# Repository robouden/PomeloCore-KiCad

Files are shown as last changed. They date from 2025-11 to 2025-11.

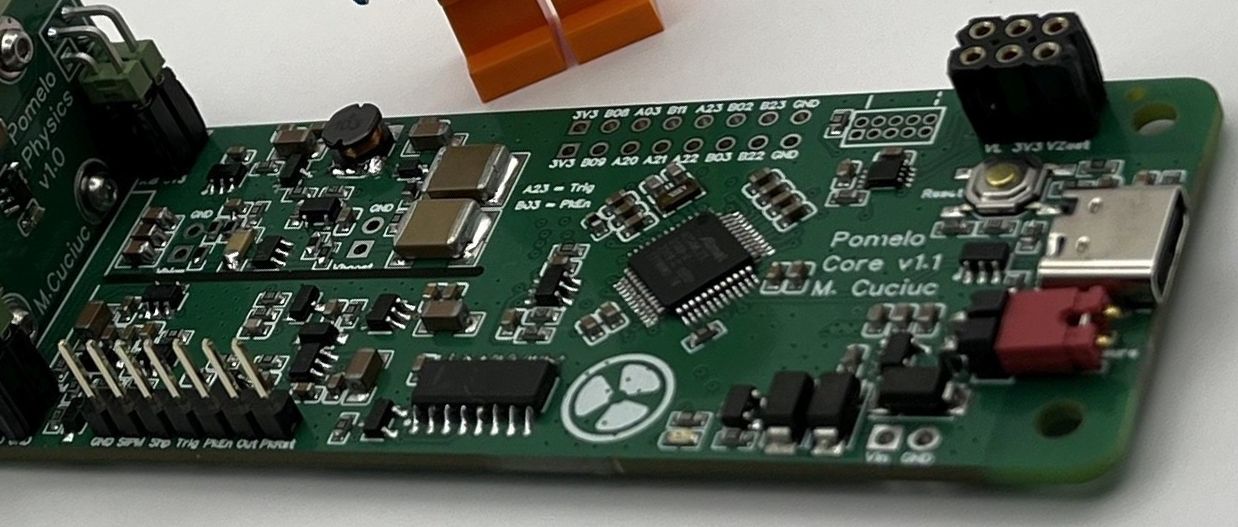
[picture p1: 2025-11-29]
Polemo Core/bGeigieScint/Images/top view 1.jpg

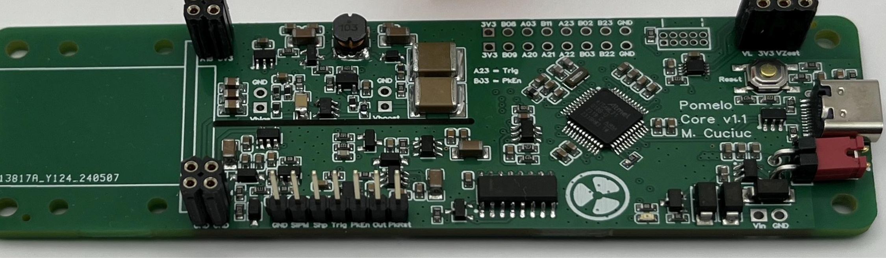
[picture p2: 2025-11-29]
Polemo Core/bGeigieScint/Images/top view 2.jpg

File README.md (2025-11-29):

# Pomelo Core





**Pomelo Core** is a compact radiation detection board featuring a Silicon Photomultiplier (SiPM) based sensor system with integrated high-voltage generation, analog signal processing, and USB connectivity.

## 📋 Features

- **Microcontroller**: ATSAML21G18B (ARM Cortex-M0+, 256KB Flash, 32KB RAM)
- **SiPM Interface**: Complete analog frontend with adjustable HV bias (30-70V)
- **Power Management**: Multi-rail power supply (3.3V, 3.0V, Vload, Vbias)
- **Connectivity**: USB-C interface with ESD protection
- **Debug**: 10-pin J-LINK SWD interface + 18 test points
- **Expansion**: Multiple GPIO headers for external interfaces
- **Compact**: 40mm × 100mm 4-layer PCB

## 🔧 Hardware Specifications

### Main Components

| Component | Part Number | Function |
|---|---|---|
| MCU | ATSAML21G18B-AUT | Main microcontroller (48-pin QFN) |
| USB | USB3.1C16PFSMT | USB-C connector (USB 2.0) |
| LDO 3.3V | XC6209F332MR-G | Main 3.3V regulator |
| LDO 3.0V | TPS7A2030PDBVR | 3.0V rail for analog |
| LDO Vload | LT3014BHVES5 | Low-noise LDO for HV control |
| OpAmp | OPA357AIDBVR | Shaper amplifier |
| Comparator | TLV3201AIDBVT | Fast comparator |
| Latch | MC14043BDR2G | Digital latch for triggering |

### SiPM Sensor

- **Part Number**: AFBR-S4N44P014M (Broadcom)
- **Type**: NUV-HD Silicon Photomultiplier
- **Active Area**: 4×4 mm²
- **Spectral Range**: 350-900 nm (peak sensitivity ~420 nm)
- **Datasheet**: [AFBR-S4N44P014M Documentation](https://docs.broadcom.com/doc/AFBR-S4N44P014M-NUV-MT-Silicon-Photomultiplier)

### Scintillator Crystal

- **Material**: CsI(Tl) - Cesium Iodide doped with Thallium
- **Dimensions**: 10 mm × 10 mm × 20 mm
- **Emission Peak**: ~550 nm (matches SiPM sensitivity)
- **Application**: Gamma ray detection coupled to SiPM

### Power Supply

- **Input**: 4.5-6V via USB-C or external connector
- **Output Rails**:
  - 3.3V @ up to 200mA (digital)
  - 3.0V @ up to 100mA (analog)
  - Vload (adjustable)
  - Vbias: 30-70V @ low current (SiPM bias)

### HV Generation

The board features an integrated **boost converter + linear regulator** topology for SiPM bias generation:

- **Boost Stage**: PWM-controlled (L1 10mH inductor, Q3 P-FET, D9 Schottky)
- **Regulation**: LT3014 ultra-low-noise LDO
- **Control**: MCU DAC output (PA02_DAC_HV) sets target voltage
- **Monitoring**: Comparator feedback (PB10_HV_COMP_OUT)
- **Output**: Adjustable 30-70V Vbias for SiPM

## 📁 Project Structure

```
PomeloCore-KiCad/
├── Polemo Core/
│   └── Polemo Core 2/
│       ├── Polemo Core 2.kicad_pro       # KiCad project file
│       ├── Polemo Core 2.kicad_sch       # Schematic (organized in functional blocks)
│       ├── Polemo Core 2.kicad_pcb       # PCB layout (4-layer, 40×100mm)
│       └── Polemo Core 2-backups/        # Automatic backups
├── BOM.csv                                # Bill of Materials
├── v1_2/                                  # Version 1.2 reference files
│   └── schematic/
│       └── PomeloCore.pdf                 # V1.2 schematic PDF
└── README.md                              # This file
```

## 🎨 Schematic Organization

The schematic is organized into **7 functional blocks**:

1. **USB & POWER INPUT**: USB-C interface, power connectors, reset button
2. **POWER MANAGEMENT**: LDOs, inductors, power distribution
3. **MCU CORE**: Microcontroller, crystal, decoupling
4. **ANALOG FRONTEND**: SiPM signal chain, opamps, comparators
5. **LOGIC & CONTROL**: Digital logic, latches, level shifters
6. **EXPANSION I/O**: Pin headers for external connections
7. **DEBUG & TEST**: J-LINK interface, test points

## 🔌 Pinout & Interfaces

### J-LINK Debug Header (10-pin)
```
1: VCC        2: SWDIO
3: GND        4: SWCLK
5: GND        6: SWO
7: NC         8: NC
9: GND       10: RESET
```

### Expansion Headers

- **H2, H3**: 7-pin GPIO expansion
- **H5**: 7-pin expansion with labeled signals
- **MEAS1**: 2-pin measurement header
- **P1, P2**: 2×2 power connectors (mirrored on Pomelo Physics board)

### Key Signals

| Signal | Description |
|---|---|
| SiPM_A | SiPM analog input |
| Vbias | SiPM bias voltage output |
| SHAPER_OUT | Shaped pulse output |
| PA02_DAC_HV | HV control DAC output |
| PA10_PWM | Boost converter PWM |
| PB03_PEAKDET_EN | Peak detector enable |
| PA23_TRG_OUT | Trigger output |

## 📊 Version History

### V1.3 (Current)
**Major improvements over V1.2:**

✅ **Added (47 components)**:
- USB-C connector (USBC1)
- Reset button (BUT1)
- J-LINK debug header
- 18 test points (TP1-TP18)
- Additional transistors (Q4, Q5) and diodes (D6, D8, D10)
- 15 new resistors for better signal conditioning

✅ **Changed**:
- C44: 1uF → 4.7uF
- C45: 4.7uF → 1uF
- H2, H3: 6-pin → 7-pin headers (expanded)

✅ **Enhanced**:
- Better debugging capability
- Improved power filtering
- More flexible I/O expansion

### V1.2 (Legacy)
- Initial production version
- PDF schematic available in `v1_2/schematic/`

## 🚀 Getting Started

### Prerequisites

- **KiCad 9.0** or later
- Basic understanding of radiation detection and SiPM operation
- JTAG/SWD programmer (e.g., J-Link, ST-Link)

### Opening the Project

1. Clone this repository
2. Open `Polemo Core/Polemo Core 2/Polemo Core 2.kicad_pro` in KiCad
3. The schematic shows functional blocks with dashed rectangles
4. The PCB has components organized by function

### Manufacturing

**PCB Specifications:**
- **Layers**: 4 (signal/GND/VCC/signal)
- **Dimensions**: 40mm × 100mm
- **Thickness**: 1.6mm
- **Copper**: 35μm (1oz) on all layers
- **Min Track/Space**: 0.15mm / 0.15mm (for 0805 components)
- **Finish**: HASL or ENIG recommended
- **Solder Mask**: Green (top and bottom)

**Assembly Notes:**
- Minimum component size: 0805 for passives
- QFN-48 MCU requires reflow soldering
- LDOs are SOT-23-5 packages
- Test points for easy debugging

## 📝 Design Notes

### Power Planes
- **Layer 1 (In1.Cu)**: GND plane - solid pour for low noise
- **Layer 2 (In2.Cu)**: VCC plane - split for 3.3V/3.0V rails

### Critical Traces
- Keep SiPM analog traces short and shielded
- HV traces (Vbias) should be isolated from digital signals
- Crystal traces should be short with GND guard ring

### Component Placement
Components are organized into functional blocks:
- Power supply on left side
- MCU in center
- Analog section on right
- Digital logic bottom-right

## 🔬 Applications

- Radiation detection and measurement
- Scintillation counting
- Environmental monitoring
- Educational radiation physics
- DIY Geiger counter replacement with better sensitivity

## 👥 Credits

**Designer**: M. Cuciuc
**Organization**: Safecast
**Date**: 2024-2025

## 📄 License

This hardware design is open source. Please check individual files for specific license terms.

Firmware and software components may have separate licenses.

## 🤝 Contributing

Contributions are welcome! Please:

1. Fork the repository
2. Create a feature branch
3. Make your changes
4. Submit a pull request

For major changes, please open an issue first to discuss what you would like to change.

## 📞 Support

- **Project Page**: [Pomelo on Crowd Supply](https://www.crowdsupply.com/pomelo-instrumentation/pomelo)
- **Safecast**: [https://safecast.org](https://safecast.org)
- Report issues through the repository's issue tracker

## ⚠️ Safety Warning

This board generates **high voltage** (up to 70V) for SiPM biasing. Handle with care:
- Do not touch HV traces while powered
- Use proper ESD protection
- Follow safe electronics handling practices
- Designed for educational and research purposes

---

**Made with ❤️ for the radiation detection community**

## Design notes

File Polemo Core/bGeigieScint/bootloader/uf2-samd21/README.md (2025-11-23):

# UF2 Bootloader

This repository contains a bootloader, derived from Atmel's SAM-BA,
which in addition to the USB CDC (serial) protocol, also supports
the USB MSC (mass storage).

## Features this version

- Support Pomelo Core board

This is adapted from the SAML21 version of the UF2 bootloader found on [the ElectronicCats github](https://github.com/ElectronicCats/uf2-samd21)

## UF2

**UF2 (USB Flashing Format)** is a name of a file format, developed by Microsoft, that is particularly
suitable for flashing devices over MSC devices. The file consists
of 512 byte blocks, each of which is self-contained and independent
of others.

Each 512 byte block consist of (see `uf2format.h` for details):
* magic numbers at the beginning and at the end
* address where the data should be flashed
* size of data
* data (up to 476 bytes; for SAMD it's 256 and 128 bytes so it's easy to flash in one go)

Thus, it's really easy for the microcontroller to recognize a block of
a UF2 file is written and immediately write it to flash.

* **UF2 specification repo:** https://github.com/Microsoft/uf2
* [#DeskOfLadyada UF24U ! LIVE @adafruit #adafruit #programming](https://youtu.be/WxCuB6jxLs0)

## Features

* USB CDC (Serial emulation) monitor mode compatible with Arduino
  (including XYZ commands) and BOSSA flashing tool
* USB MSC interface for writing UF2 files
* reading of the contests of the flash as an UF2 file via USB MSC
* UART Serial (real serial wire) monitor mode (typically disabled due to space constraints)
* In-memory logging for debugging - use the `logs` target to extract the logs using `openocd`
* double-tap reset to stay in the bootloader mode
* automatic reset after UF2 file is written

## Board identification

Configuration files for board `foo` are in `boards/foo/board_config.h` and `board.mk`. You can
build it with `make BOARD=foo`. You can also create `Makefile.user` file with `BOARD=foo`
to change the default.

The board configuration specifies the USB vendor/product name and ID,
as well as the volume label (main thing that the operating systems show).

There is also `BOARD_ID`, which is meant to be machine-readable and specific
to a given version of board hardware. The programming environment might use
this to suggest packages to be imported (i.e., a package for a particular
external flash chip, SD card etc.).

These configuration values can be read from `INFO_UF2.TXT` file.
Presence of this file can be tested to see if the board supports `UF2` flashing,
while contest, particularly `Board-ID` field, can be used for feature detection.

The current flash contents of the board is exposed as `CURRENT.UF2` file.
This file includes the bootloader address space. The last word of bootloader
space points to the string holding the `INFO_UF2.TXT` file, so it can be parsed
by a programming environment to determine which board does the `.UF2` file comes from.

## Handover

When the user space application implements the USB MSC protocol, it's possible to
handover execution to the bootloader in the middle of MSC file transfer,
when the application detects that a UF2 block is written.

Details are being finalized.

## Bootloader update

The bootloader will never write to its own flash area directly.
However, the user code can write there.
Thus, to update the bootloader, one can ship a user-space program,
that contains the new version of the bootloader and copies it to the
appropriate place in flash.

Such a program is generated during build in files `update-bootloader*.uf2`.
If you're already running UF2 bootloader, the easiest way to update
it, is to just copy this file to the exposed MSD drive.

The build also generates `update-bootloader*.ino` with an equivalent Arduino
sketch. You can copy&paste it into Arduino IDE and upload it to the device.

## Fuses

### SAMD21

The SAMD21 supports a `BOOTPROT` fuse, which write-protects the flash area of
the bootloader. Changes to this fuse only take effect after device reset.

OpenOCD exposes `at91samd bootloader` command to set this fuse. **This command is buggy.**
It seems to reset both fuse words to `0xffffffff`, which prevents the device
from operating correctly (it seems to reboot very frequently).
In `scripts/fuses.tcl` there is an OpenOCD script
which correctly sets the fuse. It's invoked by `dbgtool.js fuses`. It can be also
used to reset the fuses to sane values - just look at the comment at the top.

The bootloader update programs (both the `.uf2` file and the Arduino sketch)
clear the `BOOTPROT` (i.e., set it to `0x7`) before trying to flash anything.
After flashing is done, they set `BOOTPROT` to 8 kilobyte bootloader size (i.e, `0x2`).

### SAMD51

The SAMD51s bootloader protection can be temporarily disabled through an NVM
command rather than a full erase and write of the AUX page. The boot protection
will be checked and set by the self updaters.

So, if you've used self-updaters but want to load it directly, then you'll need
to temporarily turn off the protection. In gdb the command is:

`set ((Nvmctrl  *)0x41004000UL)->CTRLB.reg = (0xA5 << 8) | 0x1a`

## Build

### Requirements

* `make` and an Unix environment
* `node`.js in path (optional)
* `arm-none-eabi-gcc` in the path (the one coming with Yotta will do just fine). You can get the latest version from ARM: https://developer.arm.com/open-source/gnu-toolchain/gnu-rm/downloads
* `openocd` - you can use the one coming with Arduino (after your install the M0 board support)

Atmel Studio is not supported.

You will need a board with `openocd` support.

Arduino Zero (or M0 Pro) will work just fine as it has an integrated USB EDBG
port. You need to connect both USB ports to your machine to debug - one is for
flashing and getting logs, the other is for the exposed MSC interface.

Otherwise, you can use other SAMD21 board and an external `openocd` compatible
debugger. IBDAP is cheap and seems to work just fine. Another option is to use
Raspberry Pi and native bit-banging.

`openocd` will flash 16k, meaning that on SAMD21 the beginning of user program (if any) will
be overwritten with `0xff`. This also means that after fresh flashing of bootloader
no double-tap reset is necessary, as the bootloader will not try to start application
at `0xffffffff`.

### Build commands

The default board is `zero`. You can build a different one using:

```
make BOARD=metro_m0
```

If you're working on different board, it's best to create `Makefile.local`
with say `BOARD=metro` to change the default.
The names `zero` and `metro` refer to subdirectories of `boards/`.

There are various targets:
* `all` - just compile the board
* `burn` or `b` - compile and deploy to the board using openocd
* `logs` or `l` - shows logs
* `run` or `r` - burn, wait, and show logs

Typically, you will do:

```
make r
```

### Configuration

There is a number of configuration parameters at the top of `uf2.h` file.
Adjust them to your liking.

By default, you cannot enable all the features, as the bootloader would exceed
the 8k(SAMD21)/16k(SAMD51) allocated to it by Arduino etc. It will assert on startup that it's not bigger
than 8k(SAMD21)/16k(SAMD51). Also, the linker script will not allow it.

Three typical configurations are:

* HID, WebUSB, MSC, plus flash reading via FAT; UART and CDC disabled;
  logging optional; **recommended**
* USB CDC and MSC, plus flash reading via FAT; UART disabled;
  logging optional; this may have Windows driver problems
* USB CDC and MSC, no flash reading via FAT (or at least `index.htm` disabled); UART enabled;
  logging disabled; no handover; no HID;
  only this one if you need the UART support in bootloader for whatever reason

CDC and MSC together will work on Linux and Mac with no drivers.
On Windows, if you have drivers installed for the USB ID chosen,
then CDC might work and MSC will not work;
otherwise, if you have no drivers, MSC will work, and CDC will work on Windows 10 only.
Thus, it's best to set the USB ID to one for which there are no drivers.

The bootloader sits at 0x00000000, and the application starts at 0x00002000 (SAMD21) or 0x00004000 (SAMD51).

## Code of Conduct

This project has adopted the [Microsoft Open Source Code of Conduct](https://opensource.microsoft.com/codeofconduct/). For more information see the [Code of Conduct FAQ](https://opensource.microsoft.com/codeofconduct/faq/) or contact [opencode@microsoft.com](mailto:opencode@microsoft.com) with any additional questions or comments.

## License

See THIRD-PARTY-NOTICES.txt for the original SAM-BA bootloader license from Atmel.

The new code is licensed under MIT.

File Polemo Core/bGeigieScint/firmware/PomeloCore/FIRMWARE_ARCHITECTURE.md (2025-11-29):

# PomeloCore Firmware Architecture

## Overview

PomeloCore is a sophisticated gamma spectroscopy system firmware built on an Atmel SAML21G18B ARM Cortex-M0+ microcontroller. The system provides real-time radiation detection, multi-channel analysis (MCA), and dosimetry capabilities for scintillation detectors with SiPM readout.

## System Block Flow

```
┌─────────────────────────────────────────────────────────────────┐
│                         SYSTEM INITIALIZATION                   │
│  main.c:2163                                                    │
├─────────────────────────────────────────────────────────────────┤
│  • System clock init (DFLL 48MHz or OSC16M)                     │
│  • GPIO configuration (LED, AFE, HV, triggers, coincidence)     │
│  • Load parameters from NVM                                     │
│  • Initialize peripherals (UART, USB, I2C, ADC, DAC, RTC)       │
└──────────────────────┬──────────────────────────────────────────┘
                       │
                       ▼
┌─────────────────────────────────────────────────────────────────┐
│                        MAIN LOOP (while 1)                      │
│  main.c:2294                                                    │
├─────────────────────────────────────────────────────────────────┤
│  ┌──────────────┐  ┌──────────────┐  ┌──────────────────────┐   │
│  │ USB Handler  │  │ UART Handler │  │  List Output FIFO    │   │
│  │ (CDC Device) │  │ (921600 baud)│  │  Handler             │   │
│  └──────┬───────┘  └──────┬───────┘  └──────┬───────────────┘   │
│         │                 │                  │                  │
│         └─────────────────┴──────────────────┘                  │
│                           │                                     │
│                           ▼                                     │
│              ┌────────────────────────┐                         │
│              │  Command Parser        │                         │
│              │  main.c:1896           │                         │
│              │  (JSON protocol)       │                         │
│              └────────────────────────┘                         │
└─────────────────────────────────────────────────────────────────┘
                           │
         ┌─────────────────┼─────────────────┐
         │                 │                 │
         ▼                 ▼                 ▼
┌─────────────────┐ ┌────────────┐ ┌────────────────┐
│ DATA ACQUISITION│ │ PARAMETER  │ │  CALIBRATION   │
│                 │ │ MANAGEMENT │ │  & DIAGNOSTICS │
├─────────────────┤ ├────────────┤ ├────────────────┤
│ • Start/Stop    │ │ • Set HV   │ │ • ADC calib    │
│ • Histogram     │ │ • Threshold│ │ • Temp comp    │
│ • Dosimetry     │ │ • Save NVM │ │ • Ramp gen     │
│ • Config read   │ │ • Load NVM │ │ • HV load test │
└─────────────────┘ └────────────┘ └────────────────┘
         │
         ▼
┌─────────────────────────────────────────────────────────────────┐
│                   INTERRUPT SERVICE ROUTINES                    │
├─────────────────────────────────────────────────────────────────┤
│                                                                 │
│  ┌────────────────────────────────────────────────────────────┐ │
│  │ GAMMA TRIGGER ISR (main.c:192)                             │ │
│  │ ────────────────────────────────────────────────────────── │ │
│  │ 1. Particle detection (PIN_PA18 external interrupt)        │ │
│  │ 2. Start ADC conversion (peak detector read)               │ │
│  │ 3. Clear peak detector capacitor                           │ │
│  │ 4. Apply spectral deconvolution (pMove filter)             │ │
│  │ 5. Update histogram bins (gammaSpectrum[])                 │ │
│  │ 6. Coincidence logic (monitor PIN_PA20, ACK on PB11)       │ │
│  │ 7. List mode FIFO update                                   │ │
│  │ 8. Statistics accumulation (count, sum, sum²)              │ │
│  └────────────────────────────────────────────────────────────┘ │
│                                                                 │
│  ┌────────────────────────────────────────────────────────────┐ │
│  │ RTC PERIODIC ISR (main.c:315)                              │ │
│  │ ────────────────────────────────────────────────────────── │ │
│  │ • Temperature compensation update (every 1s)               │ │
│  │ • SiPM bias voltage adjustment based on temp               │ │
│  │ • HV load regulation                                       │ │
│  └────────────────────────────────────────────────────────────┘ │
│                                                                 │
│  ┌────────────────────────────────────────────────────────────┐ │
│  │ SYNCHRONIZER ISR (main.c:172)                              │ │
│  │ ────────────────────────────────────────────────────────── │ │
│  │ • External sync pulse handler (PIN_PB08)                   │ │
│  │ • Marker insertion in FIFO (value 9999)                    │ │
│  └────────────────────────────────────────────────────────────┘ │
│                                                                 │
│  ┌────────────────────────────────────────────────────────────┐ │
│  │ HV LOAD ISR (main.c:336)                                   │ │
│  │ ────────────────────────────────────────────────────────── │ │
│  │ • HV current monitoring (PIN_PB10)                         │ │
│  │ • Automatic boost mode switching                           │ │
│  └────────────────────────────────────────────────────────────┘ │
│                                                                 │
└─────────────────────────────────────────────────────────────────┘
         │
         ▼
┌─────────────────────────────────────────────────────────────────┐
│                      HARDWARE CONTROL LAYER                     │
├─────────────────────────────────────────────────────────────────┤
│                                                                 │
│  ┌──────────────┐  ┌──────────────┐  ┌──────────────────────┐   │
│  │ HV GENERATOR │  │  ADC/DAC     │  │  TEMPERATURE SENSOR  │   │
│  │ (main.c:543) │  │ (main.c:677) │  │  (main.c:979)        │   │
│  ├──────────────┤  ├──────────────┤  ├──────────────────────┤   │
│  │• TCC PWM     │  │• ADC0 Ch8    │  │• I2C TMP116/TMP451   │   │
│  │• Dual boost  │  │• DAC0/1      │  │• SiPM temp comp      │   │
│  │• HV crowbar  │  │• Threshold   │  │• Auto voltage adj    │   │
│  │• Load sense  │  │• Peak detect │  │                      │   │
│  └──────────────┘  └──────────────┘  └──────────────────────┘   │
│                                                                 │
│  ┌──────────────────────────────────────────────────────────┐   │
│  │ COINCIDENCE DETECTION (main.c:401)                       │   │
│  ├──────────────────────────────────────────────────────────┤   │
│  │ • Configurable Analog Comparator + CCL logic             │   │
│  │ • Monitor input (PA20) / ACK output (PB11)               │   │
│  │ • Separate coincidence histogram                         │   │
│  └──────────────────────────────────────────────────────────┘   │
│                                                                 │
└─────────────────────────────────────────────────────────────────┘
         │
         ▼
┌─────────────────────────────────────────────────────────────────┐
│                      DATA OUTPUT STREAMS                        │
├─────────────────────────────────────────────────────────────────┤
│                                                                 │
│  • Spectrum histogram (1024 bins, JSON)                         │
│  • Real-time pulse output (UART/USB)                            │
│  • List mode with timestamps                                    │
│  • Dosimetry calculations (CPM, μSv/h)                          │
│  • System telemetry (temp, uptime, status)                      │
│                                                                 │
└─────────────────────────────────────────────────────────────────┘
```

## Hardware Platform

### Microcontroller

- **MCU**: Atmel SAML21G18B
- **Core**: ARM Cortex-M0+
- **Clock**: 48 MHz (DFLL) / 16 MHz (OSC16M)
- **Flash**: 256 KB
- **RAM**: 32 KB

### Key Peripherals Used

- **ADC**: 12-bit, used for peak detector readout
- **DAC**: Dual channel for HV control and threshold
- **TCC**: Timer/Counter for PWM HV generation
- **RTC**: Real-time counter for timing and periodic tasks
- **I2C**: Temperature sensor communication
- **UART**: 921600 baud host communication
- **USB**: CDC device class
- **EXTINT**: External interrupt for trigger detection
- **AC/CCL**: Analog comparator and configurable custom logic for coincidence

## Software Architecture

### Main Components

#### 1. Initialization (main.c:2163)

- System clock configuration
- GPIO pin setup for all detector interfaces
- Peripheral initialization (UART, USB, I2C, ADC, DAC, RTC)
- Parameter loading from NVM
- Initial state configuration

#### 2. Main Loop (main.c:2294)

The main loop operates in a continuous polling mode:

- **USB Data Handler**: Processes USB CDC commands
- **UART Data Handler**: Processes UART serial commands
- **List Mode FIFO**: Outputs event data when enabled
- **Sleep Management**: Power optimization when idle

#### 3. Command Interface (main.c:1896)

The system uses a JSON-based protocol over USB/UART:

**Commands:**

- `h` - Get histogram data
- `s` - Get system status
- `c` - Get configuration
- `x` - Start detector (power on)
- `z` - Stop detector (power off)
- `q` - Query parameters (debug)
- Parameter setting commands (multi-byte protocol)

**Response Format:**

```json
{
  "type": "spectrum|system|config",
  "payload": { ... }
}
```

#### 4. Data Acquisition (main.c:1412)

**DAQ Start Sequence:**

1. Clear spectrum arrays
2. Reset counters
3. Configure RTC compare for timed acquisition
4. Enable interrupt-driven data collection

**DAQ Features:**

- Continuous or timed acquisition modes
- 1024-channel histogram
- Separate coincidence histogram
- Real-time statistics (count, sum, sum of squares)

#### 5. Interrupt Service Routines

##### Gamma Trigger ISR (main.c:192)

The heart of the system - triggered on each particle detection:

1. Read ADC value from peak detector
2. Clear peak detector capacitor
3. Apply spectral deconvolution filter (pMove matrix)
4. Bin event in histogram
5. Handle coincidence logic if enabled
6. Update list mode FIFO
7. Accumulate statistics

**Performance Note:** ISR is optimized for minimal latency to handle high count rates.

##### RTC Periodic ISR (main.c:315)

Runs every second for system maintenance:

- Temperature compensation for SiPM bias
- HV load monitoring and regulation
- Timed acquisition stop

##### Synchronizer ISR (main.c:172)

Handles external synchronization pulses:

- Inserts markers (value 9999) in list mode data
- Allows multi-detector time correlation

##### HV Load ISR (main.c:336)

Monitors high voltage system:

- Measures HV current draw
- Switches between normal/boost modes automatically
- Ensures stable detector operation

### Hardware Control Functions

#### High Voltage System (main.c:543, 592, 651)

- **PWM-based boost converter** with dual mode operation
- **HV enable/disable** with crowbar protection
- **Dynamic boost switching** based on load
- **Temperature-compensated SiPM bias** for gain stability

#### ADC/DAC Management (main.c:677, 708)

- **ADC**: Reads peak detector output (12-bit)
- **DAC0**: Controls high voltage level
- **DAC1**: Sets discriminator threshold
- **Calibration support** for linearity correction

#### Temperature Sensing (main.c:979)

- **Supports TMP116 or TMP451** sensors via I2C
- **Automatic detection** of sensor type
- **Real-time compensation** of SiPM operating voltage
- **Temperature coefficient** stored in NVM parameters

#### Coincidence Detection (main.c:401, 428)

- **Hardware-based** using AC and CCL modules
- **Monitor line** (PA20) for incoming coincidence signals
- **ACK line** (PB11) for daisy-chain operation
- **Separate histogram** for coincidence events
- **Configurable enable/disable**

### Data Structures

#### Core Parameters (nvm_params.h:3)

Stored in NVM, contains system configuration:

```c
struct core_params {
    uint8_t version;
    float vDac[2];              // HV DAC calibration
    float iMeas[3];             // Current measurement cal
    uint16_t threshold;         // Discriminator level
    uint8_t sys_outputs;        // Output enable flags
    uint8_t sys_pulseChar;      // Pulse character for list mode
    bool sys_power;             // Power state
    bool sys_coincidence;       // Coincidence mode enable
};
```

#### Physics Parameters (nvm_params.h:28)

Detector-specific calibration data:

```c
struct physics_params {
    uint8_t version;
    float sipm_vMin;            // SiPM minimum voltage
    float sipm_vMax;            // SiPM maximum voltage
    float sipm_v0deg;           // SiPM voltage at 0°C
    float sipm_vTempComp;       // Temperature coefficient
    float ecal[3];              // Energy calibration polynomial
    float uSvph_constant;       // Dose rate conversion
    char detString[64];         // Detector description
    uint8_t tempType;           // Temperature sensor type
};
```

### List Mode Output

The system supports multiple list mode configurations (bit flags in `sys_outputs`):

**UART Outputs:**

- `LIST_UART_PULSE` (bit 0): Simple pulse character per event
- `LIST_UART_FAST_PULSE` (bit 1): Fast pulse in ISR (minimal latency)
- `LIST_UART_ENERGY` (bit 2): Energy value per event
- `LIST_UART_ENERGY_TS` (bit 3): Energy + timestamp

**USB Outputs:**

- `LIST_USB_PULSE` (bit 4): Pulse character via USB
- `LIST_USB_ENERGY` (bit 5): Energy value via USB
- `LIST_USB_ENERGY_TS` (bit 6): Energy + timestamp via USB

### Spectral Deconvolution

The firmware implements a sophisticated **spectral unfolding algorithm** using a probability matrix `pMove[1024][9]`:

1. Each ADC bin has a probability distribution for spreading counts
2. Corrects for detector response function
3. Improves energy resolution
4. Applied in real-time during acquisition (main.c:217-230)

### Parameter Management

#### Load Parameters (main.c:1499)

- Reads `core_params` and `physics_params` from NVM
- Performs version checking and upgrades old formats
- Validates data integrity

#### Apply Parameters (main.c:2136)

- Configures hardware based on loaded parameters
- Sets HV, threshold, output modes
- Enables/disables coincidence

#### Save Parameters

- Writes updated parameters back to NVM
- Preserves calibration across power cycles

### Bootloader Interface

The firmware supports double-tap reset to bootloader (main.c:2411):

- Magic value `0xf01669ef` written to end of RAM
- Allows firmware updates without hardware programmer
- UF2 bootloader compatible (SAM-BA protocol)

## Communication Protocols

### UART Interface

- **Baud Rate**: 921600 bps
- **Format**: 8N1
- **Flow Control**: None
- **Buffer**: 128 bytes circular buffer with interrupt-driven RX
- **Pin Mapping**: PA12 (TX), PA13 (RX) on SERCOM2

### USB Interface

- **Class**: CDC (Communications Device Class)
- **Speed**: Full Speed (12 Mbps)
- **Enumeration**: Acts as virtual serial port
- **Power Detection**: VBUS sensing on PA27

### I2C Interface

- **Mode**: Master
- **Speed**: 100 kHz (standard mode)
- **Devices**: TMP116 or TMP451 temperature sensors
- **Pin Mapping**: Configured in ASF

## Key Features

1. **1024-Channel Spectroscopy**: High-resolution multi-channel analyzer
2. **Real-Time Processing**: All processing in ISR, no polling delays
3. **Temperature Compensation**: Automatic SiPM bias adjustment for stable gain
4. **Coincidence Mode**: Multi-detector anti-coincidence or coincidence
5. **List Mode**: Event-by-event data with timestamps
6. **Dual Interface**: Simultaneous USB and UART operation
7. **Persistent Calibration**: NVM storage of all parameters
8. **Spectral Deconvolution**: Real-time unfolding for improved resolution
9. **Dosimetry**: CPM and dose rate calculations
10. **Flexible Outputs**: Multiple data streaming options
11. **HV Auto-Regulation**: Adaptive boost converter for stable operation
12. **Bootloader Support**: Easy firmware updates

## Power Management

The firmware includes power optimization features:

- **Clock switching**: DFLL (48 MHz) for USB, OSC16M (16 MHz) for standalone
- **Sleep modes**: Can enter standby when inactive
- **Peripheral power gating**: DAC/HV disabled when detector off
- **USB detection**: Automatic enumeration/de-enumeration

## Memory Usage

- **Spectrum Buffer**: 4 KB (1024 × 32-bit)
- **Coincidence Spectrum**: 4 KB (1024 × 32-bit)
- **List Mode FIFO**: 512 bytes (128 × 16-bit + 128 × 32-bit)
- **ASF Framework**: ~50 KB Flash
- **Application Code**: ~20 KB Flash
- **Stack/Heap**: ~8 KB RAM

## Build Configuration

### PlatformIO Settings (platformio.ini)

- **Platform**: atmelsam
- **Board**: saml21_xpro_b (custom board definition)
- **Framework**: None (bare metal with ASF)
- **Optimization**: -Os (size optimization)
- **Bootloader Offset**: Custom linker script

### Compilation Flags

- Standard: C99 with GNU extensions
- Warnings: Maximum (-Wall and many specific warnings)
- Math: ARM CMSIS DSP support
- Async Drivers: All peripherals use callback mode

## Development Notes

### Code Structure

- **Single file architecture**: All application code in main.c (2415 lines)
- **ASF integration**: Atmel Software Framework for peripheral drivers
- **Minimal dependencies**: Optimized for embedded constraints

### Future Enhancements

Potential areas for improvement:

- Modular code organization (separate files for subsystems)
- DMA for ADC/UART to reduce ISR overhead
- SD card support for long-term data logging
- Network interface (WiFi/Ethernet module)
- OLED display support
- Battery management for portable operation

## References

- **Hardware**: PomeloCore PCB schematics in parent directory
- **MCU Datasheet**: SAML21 Family Datasheet (Microchip)
- **ASF Documentation**: Atmel Software Framework API reference
- **Bootloader**: UF2 bootloader for SAMD/SAML (Adafruit/Microsoft)

---

**Document Version**: 1.0
**Firmware Version**: Based on commit 0c74e4e
**Date**: 2025-11-25
**Author**: Generated from source code analysis

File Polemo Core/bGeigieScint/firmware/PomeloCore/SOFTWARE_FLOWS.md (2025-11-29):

# PomeloCore Firmware Software Flow Summary

### **1. Initialization Flow**
The system starts by configuring hardware and restoring state.

*   **System & Power**: Initialize system clocks, voltage regulators, and NVM (Flash) settings.
*   **GPIO Configuration**: Set up pins for LED, USB VBUS, Analog Front End (AFE), Peak Detector, Ramp Generator, and Triggers.
*   **Peripherals Setup**:
    *   **RTC & Timers**: For timekeeping and gamma pulse timing.
    *   **EIC**: External Interrupts for triggers.
    *   **ADC & DAC**: For sampling signals and controlling High Voltage (HV).
    *   **I2C**: For external sensors (Temperature).
    *   **UART & USB**: For communication.
*   **State Restoration**: Load parameters from NVM (Flash) and apply them (HV settings, coincidence mode, etc.).

### **2. Main Loop Flow**
The infinite loop continuously handles communication, data processing, and power management.

```mermaid
graph TD
    Start(Start Loop) --> USB_Check{USB Connected?}
    USB_Check -- Yes --> USB_Handler[Process USB Data]
    USB_Check -- No --> UART_Handler
    USB_Handler --> UART_Handler[Process UART Data]
    
    UART_Handler --> Data_Out{Data Output Pending?}
    Data_Out -- Yes --> Process_FIFO[Process Gamma FIFO]
    Process_FIFO --> Send_Data[Send Pulse/Energy Data to USB/UART]
    Data_Out -- No --> VBUS_Check
    Send_Data --> VBUS_Check
    
    VBUS_Check{VBUS Changed?}
    VBUS_Check -- Plugged --> Enable_USB[Enable USB & High Perf Clock]
    VBUS_Check -- Unplugged --> Disable_USB[Disable USB & Low Power Clock]
    VBUS_Check -- No Change --> Temp_Comp
    
    Enable_USB --> Temp_Comp
    Disable_USB --> Temp_Comp
    
    Temp_Comp{Temp Comp Run?}
    Temp_Comp -- Yes --> Update_HV[Update HV Bias]
    Temp_Comp -- No --> Sync_Trig
    Update_HV --> Sync_Trig
    
    Sync_Trig{Sync Trigger?}
    Sync_Trig -- Yes --> Gen_Pulse[Generate Sync Pulse]
    Sync_Trig -- No --> Sleep_Check
    Gen_Pulse --> Sleep_Check
    
    Sleep_Check{Can Sleep & No USB?}
    Sleep_Check -- Yes --> Sleep[Enter Standby Mode]
    Sleep_Check -- No --> Start
    Sleep --> Start
```

### **3. Command Processing Flow**
Incoming characters from USB or UART trigger the `command_data_handler`.

*   **`g`**: Get CPM (Counts Per Minute).
*   **`u`**: Get uSv/h (Dose rate).
*   **`m`**: Measure (Returns JSON with CPM, uSv/h, Temperature).
*   **`i`**: Get SiPM current and diagnostics.
*   **`r`**: Reload parameters from Flash.
*   **`p`**: Enter Parameter Input Mode (Accepts configuration string).
*   **`/`**: Enable HV Boost.
*   **`*`**: Disable HV Boost.

### **4. Key Interrupt/Background Tasks**
*   **Trigger Callback**: Detects radiation pulses, captures peak energy, and stores in `gammaFifo`.
*   **Timer/RTC Callbacks**: Manage measurement windows and periodic tasks.
*   **HV Load Callback**: Monitors the current draw of the High Voltage supply.

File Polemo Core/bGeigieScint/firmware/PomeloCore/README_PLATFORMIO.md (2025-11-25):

# PomeloCore - PlatformIO Build Instructions

## Overview

This project has been configured to build with PlatformIO while maintaining the original Atmel Software Framework (ASF) codebase. The source code remains unchanged from the Atmel Studio version.

## Prerequisites

1. **PlatformIO Core** or **PlatformIO IDE**
   - Install via: `pip install platformio` or use VS Code extension
   - Documentation: https://platformio.org/install

2. **ARM GCC Toolchain** (automatically installed by PlatformIO)

## Project Structure

```
PomeloCore/
├── platformio.ini          # PlatformIO configuration
├── extra_script.py         # Post-build UF2 conversion script
├── uf2conv.py             # UF2 converter (from Atmel Studio)
├── uf2families.json       # UF2 family definitions
├── PomeloCore/
│   └── src/               # All source code (unchanged)
│       ├── main.c
│       ├── nvm_params.c
│       ├── config/
│       └── ASF/           # Atmel Software Framework
└── .pio/                  # PlatformIO build output (generated)
```

## Building the Firmware

### Command Line

```bash
# Navigate to project directory
cd "/home/rob/Documents/Safecast/PomeloCore-KiCad/Polemo Core/Polemo Core 2/firmware/PomeloCore"

# Build firmware
pio run

# Clean build
pio run -t clean

# Verbose build output
pio run -v
```

### Build Output

After successful build, you'll find:
- **ELF file**: `.pio/build/saml21g18b/firmware.elf`
- **BIN file**: `.pio/build/saml21g18b/firmware.bin`
- **UF2 file**: `PomeloCore.uf2` (in project root)

## Uploading Firmware

### Via UF2 Bootloader (Recommended)

1. Build the firmware: `pio run`
2. Put device in bootloader mode (double-tap reset button)
3. Copy `PomeloCore.uf2` to the UF2 drive that appears
4. Device will automatically reset and run new firmware

### Via SWD/JTAG

```bash
# Using EDBG debugger
pio run -t upload

# Specify upload port
pio run -t upload --upload-port /dev/ttyACM0
```

## Serial Monitor

```bash
# Open serial monitor at 921600 baud
pio device monitor -b 921600

# Or specify port
pio device monitor -b 921600 -p /dev/ttyACM0
```

## Debugging

```bash
# Start debug session (requires EDBG debugger)
pio debug
```

## Configuration Details

### MCU Settings
- **Chip**: ATSAML21G18B
- **CPU Frequency**: 16 MHz (configurable via clocks)
- **Flash**: 256 KB
- **RAM**: 32 KB + 8 KB Low Power RAM

### Build Flags
All compiler flags from Atmel Studio are preserved:
- Optimization: `-Os` (size)
- Callback modes enabled for all peripherals
- USB Device LPM support
- Float printf support

### Linker Script
Uses custom bootloader linker script:
`PomeloCore/src/ASF/sam0/utils/linker_scripts/saml21/gcc/saml21j18b_flash_bootloader.ld`

## Troubleshooting

### Build Errors

**Include file not found**:
- Verify all ASF files are present in `PomeloCore/src/ASF/`
- Check include paths in `platformio.ini`

**Linker errors**:
- Ensure CMSIS math library exists: `PomeloCore/src/ASF/thirdparty/CMSIS/Lib/GCC/libarm_cortexM0l_math.a`
- Verify linker script path is correct

**UF2 conversion fails**:
- Check that `uf2conv.py` exists in project root
- Ensure Python 3 is installed
- Verify `uf2families.json` is present

### Upload Issues

**Device not found**:
- Check USB connection
- Verify device is in bootloader mode
- Try different USB cable/port

**Upload fails**:
- Ensure no other program is using the serial port
- Check upload protocol in `platformio.ini`

## Comparison with Atmel Studio

### What's the Same
- All source code (no changes required)
- Compiler flags and optimization settings
- Linker configuration
- Output binary (functionally identical)
- ASF framework version

### What's Different
- Build system (PlatformIO instead of Atmel Studio)
- Build directory (`.pio/` instead of `Debug/` or `Release/`)
- Configuration file (`platformio.ini` instead of `.cproj`)

## Advanced Usage

### Custom Build Flags

Edit `platformio.ini` to add custom flags:
```ini
build_flags = 
    -DMY_CUSTOM_FLAG=1
```

### Multiple Build Configurations

Create additional environments in `platformio.ini`:
```ini
[env:debug]
build_type = debug
build_flags = -DDEBUG -g

[env:release]
build_type = release
build_flags = -DNDEBUG -Os
```

Build specific environment:
```bash
pio run -e debug
pio run -e release
```

## Migration Notes

This project uses the deprecated Atmel Software Framework (ASF). For long-term maintainability, consider migrating to:
- **Microchip Harmony 3**: Modern, actively maintained framework
- **Arduino SAMD**: Simpler API, good community support

However, the current ASF-based code will continue to work with PlatformIO.

## Support

For PlatformIO issues:
- Documentation: https://docs.platformio.org/
- Community: https://community.platformio.org/

For PomeloCore hardware/firmware:
- Project repository: (add your repo URL here)

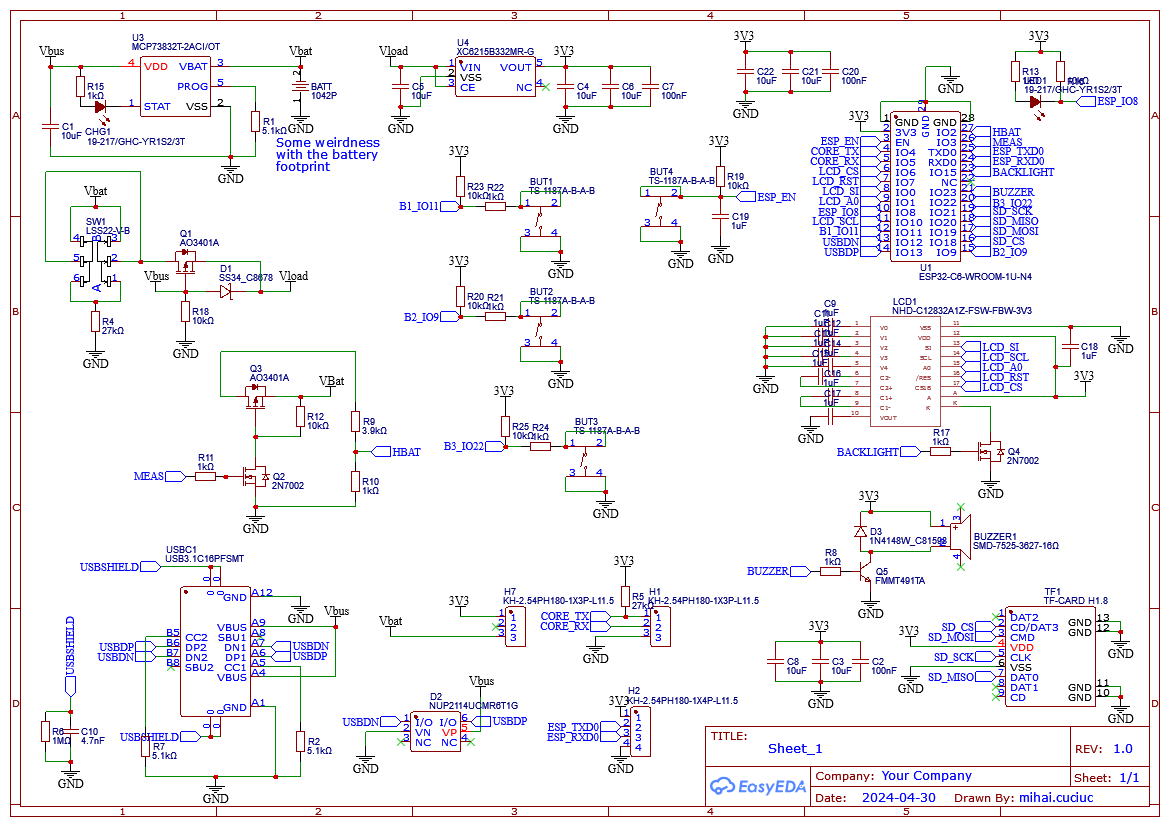
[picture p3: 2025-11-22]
Polemo Zest schematic.png

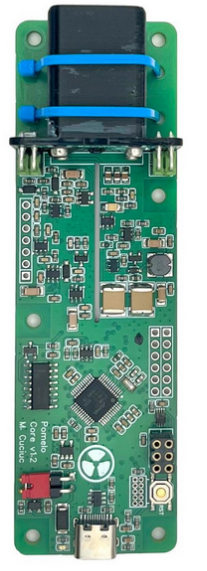
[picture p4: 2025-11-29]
Polemo Core/bGeigieScint/Images/Screenshot from 2025-11-23 09-57-53.png

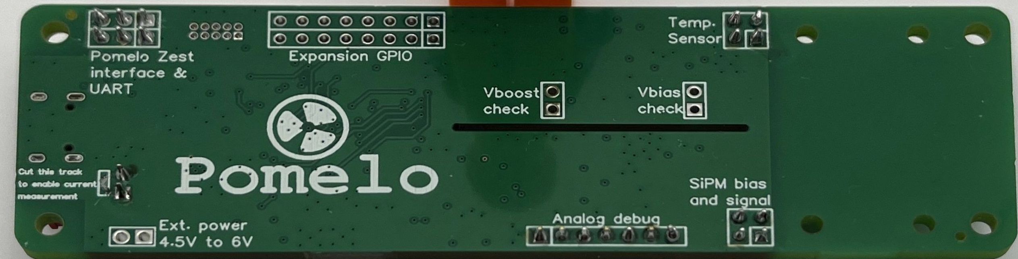
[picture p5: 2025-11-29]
Polemo Core/bGeigieScint/Images/bottom view 1.jpg

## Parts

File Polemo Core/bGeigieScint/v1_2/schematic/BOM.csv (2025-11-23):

ID | Name | Designator | Footprint | Quantity | Manufacturer Part | Manufacturer | Supplier | Supplier Part | Price
1 | 1uF | C1,C32 | C2220 | 2 | GRM55DR72D105KW01L | muRata(村田) | LCSC | C437573 | 3.298
2 | 10nF | C2,C17,C22 | C0603 | 3 | 0603B103K500NT | FH(风华) | LCSC | C57112 | 0.002
3 | 4.7uF | C3,C19,C20,C38,C39 | C1206 | 5 | 1206B475K500NT | FH(风华) | LCSC | C29823 | 0.032
4 | 10uF | C4,C5,C6,C57 | C0603 | 4 | CL10A106KP8NNNC | SAMSUNG(三星) | LCSC | C19702 | 0.005
5 | 100nF | C7,C11,C12,C18,C21,C23,C26,C27,C35,C36,C40,C41,C46,C50,C51,C53,C55,C56 | C0603 | 18 | CC0603KRX7R9BB104 | YAGEO(国巨) | LCSC | C14663 | 0.002
6 | 10nF | C8 | C1206 | 1 | 12062C103KAT2A | Kyocera AVX | LCSC | C597478 | 0.112
7 | 30pF | C9 | C0603 | 1 | 0603CG300J500NT | FH(风华) | LCSC | C1658 | 0.003
8 | 4.7nF | C10 | C0603 | 1 | 0603B472K500NT | FH(风华) | LCSC | C53987 | 0.003
9 | 1uF | C13,C14,C33,C37,C45 | C0603 | 5 | CL10A105KB8NNNC | SAMSUNG(三星) | LCSC | C15849 | 0.004
10 | 1nF | C15,C16,C24,C29,C30,C34 | C0603 | 6 | CL10B102KB8NNNC | SAMSUNG(三星) | LCSC | C1588 | 0.003
11 | 1uF | C25,C28,C31 | C0805 | 3 | 08051C105KAT2A | Kyocera AVX | LCSC | C597292 | 1.79
12 | 18pF | C42,C43 | C0603 | 2 | CL10C180JB8NNNC | SAMSUNG(三星) | LCSC | C1647 | 0.005
13 | 4.7uF | C44,C47,C48,C49,C52,C54 | C0603 | 6 | CL10A475KO8NNNC | SAMSUNG(三星) | LCSC | C19666 | 0.009
14 | NUP2114UCMR6T1G | D1 | TSOP-6_L3.0-W1.5-P0.95-LS2.8-BL | 1 | NUP2114UCMR6T1G | ON Semicon | LCSC | C393373 | 0.412
15 | BAS21HT1G | D2 | SOD-323_L1.8-W1.3-LS2.5-RD | 1 | BAS21HT1G | onsemi(安森美) | LCSC | C82466 | 0.024
16 | 1N4148W_C81598 | D3,D4,D5 | SOD-123F_L2.7-W1.6-LS3.8-RD | 3 | 1N4148W | ST(先科) | LCSC | C81598 | 0.011
17 | BAT54C,215 | D7 | SOT-23-3_L2.9-W1.6-P1.90-LS2.8-BR | 1 | BAT54C,215 | Nexperia(安世) | LCSC | C37704 | 0.01
18 | SS34_C8678 | D9 | SMA_L4.3-W2.6-LS5.2-RD | 1 | SS34 | MDD | LCSC | C8678 | 0.025
19 | KH-2.54PH180-1X3P-L11.5 | H1,H7 | HDR-TH_3P-P2.54-V-M | 2 | KH-2.54PH180-1X3P-L11.5 | kinghelm(金航标) | LCSC | C2932698 | 0.019
20 | KH-2.54PH180-1X6P-L11.5 | H2,H3 | HDR-TH_6P-P2.54-V-M-1 | 2 | KH-2.54PH180-1X6P-L11.5 | kinghelm(金航标) | LCSC | C2905486 | 0.051
21 | KH-2.54PH180-1X7P-L11.5 | H5 | HDR-TH_7P-P2.54-V-M | 1 | KH-2.54PH180-1X7P-L11.5 | kinghelm(金航标) | LCSC | C2932700 | 0.039
22 | 20021111-00010T4LF | J-LINK1 | HDR-TH_10P-P1.27-V-R2-C5-S1.27 | 1 | 20021111-00010T4LF | Amphenol ICC | LCSC | C239059 | 0.584
23 | SDR0503-103JL | L1 | SDR0503103JL | 1
24 | 10uH | L2 | L0603 | 1 | SDFL1608S100KTF | Sunlord(顺络) | LCSC | C1035 | 0.01
25 | 470Ω | L3 | L0603 | 1 | BLM18PG471SN1D | muRata(村田) | LCSC | C97853 | 0.008
26 | 19-217/GHC-YR1S2/3T | LED1 | LED0603-RD | 1 | 19-217/GHC-YR1S2/3T | EVERLIGHT(亿光) | LCSC | C72043 | 0.031
27 | KH-2.54PH90-1X2P-L13.8 | MEAS1 | HDR-TH_2P-P2.54-H-M_KH-2.54PH90-1X2P-L13.8 | 1 | KH-2.54PH90-1X2P-L13.8 | kinghelm(金航标) | LCSC | C2905424 | 0.021
28 | Header-Male-2.54_2x2 | P1,P2 | HDR-TH_4P-P2.54-V-M-R2-C2-S2.54-1 | 2 | 2.54-2*2P针 | BOOMELE(博穆精密) | LCSC | C66690 | 0.021
29 | BC847_C2910145 | Q1 | SOT-23-3_L2.9-W1.3-P1.90-LS2.4-BR | 1 | BC847 | CJ(江苏长电/长晶) | LCSC | C2910145 | 0.017
30 | MMBT5551LT1G | Q2 | SOT-23-3_L2.9-W1.3-P0.95-LS2.4-BR | 1 | MMBT5551LT1G | onsemi(安森美) | LCSC | C41095 | 0.026
31 | AO3401A | Q3 | SOT-23_L2.9-W1.3-P1.90-LS2.4-BR | 1 | AO3401A | AOS | LCSC | C15127 | 0.055
32 | 27kΩ | R1,R39 | R0603 | 2 | 0603WAF2702T5E | UNI-ROYAL(厚声) | LCSC | C22967 | 0.001
33 | 5.1kΩ | R2,R7 | R0603 | 2 | 0603WAF5101T5E | UNI-ROYAL(厚声) | LCSC | C23186 | 0.001
34 | 47kΩ | R3,R35,R36 | R0603 | 3 | 0603WAF4702T5E | UNI-ROYAL(厚声) | LCSC | C25819 | 0.001
35 | 1kΩ | R4,R9,R17,R29,R30,R33,R40 | R0603 | 7 | 0603WAF1001T5E | UNI-ROYAL(厚声) | LCSC | C21190 | 0.001
36 | 220kΩ | R5 | R0603 | 1 | 0603WAF2203T5E | UNI-ROYAL(厚声) | LCSC | C22961 | 0.001
37 | 1MΩ | R6 | R0603 | 1 | 0603WAF1004T5E | UNI-ROYAL(厚声) | LCSC | C22935 | 0.001
38 | 330kΩ | R8,R11,R12 | R0603 | 3 | 0603WAF3303T5E | UNI-ROYAL(厚声) | LCSC | C23137 | 0.001
39 | 100Ω | R10,R18,R20,R28,R32 | R0603 | 5 | 0603WAF1000T5E | UNI-ROYAL(厚声) | LCSC | C22775 | 0.001
40 | 100kΩ | R13,R16 | R0603 | 2 | 0603WAF1003T5E | UNI-ROYAL(厚声) | LCSC | C25803 | 0.001
41 | 120MΩ | R14 | R0603 | 1 | 0603WAF4704T5E | UNI-ROYAL(厚声) | LCSC | C23163 | 0.001
42 | 5.6MΩ | R15 | R0603 | 1 | 0603WAF5604T5E | UNI-ROYAL(厚声) | LCSC | C23190 | 0.001
43 | 22kΩ | R19 | R0603 | 1 | 0603WAF2202T5E | UNI-ROYAL(厚声) | LCSC | C31850 | 0.001
44 | 6.8kΩ | R21,R27 | R0603 | 2 | 0603WAF6801T5E | UNI-ROYAL(厚声) | LCSC | C23212 | 0.001
45 | 30kΩ | R22 | R0603 | 1 | 0603WAF3002T5E | UNI-ROYAL(厚声) | LCSC | C22984 | 0.001
46 | 10kΩ | R23,R37 | R0603 | 2 | 0603WAF1002T5E | UNI-ROYAL(厚声) | LCSC | C25804 | 0.001
47 | 4.7MΩ | R25 | R0603 | 1 | 0603WAF4704T5E | UNI-ROYAL(厚声) | LCSC | C23163 | 0.001
48 | 2.2kΩ | R26 | R0603 | 1 | 0603WAF2201T5E | UNI-ROYAL(厚声) | LCSC | C4190 | 0.001
49 | 510Ω | R31 | R0603 | 1 | 0603WAF5100T5E | UNI-ROYAL(厚声) | LCSC | C23193 | 0.001
50 | 200kΩ | R34 | R0603 | 1 | 0603WAF2003T5E | UNI-ROYAL(厚声) | LCSC | C25811 | 0.001
51 | 0Ω | R38 | R0603 | 1 | 0603WAF0000T5E | UNI-ROYAL(厚声) | LCSC | C21189 | 0.001
52 | TS-1187A-B-A-B | RESET1 | SW-SMD_4P-L5.1-W5.1-P3.70-LS6.5-TL-2 | 1 | TS-1187A-B-A-B | XKB Connectivity(中国星坤) | LCSC | C318884 | 0.017
53 | 1-POINT TEST POINT | TP1,TP2,TP3,TP4,TP5,TP6,TP7,TP8,TP9,TP10,TP11,TP12,TP13,TP14,TP15,TP16,TP17 | 1-POINT_TEST-POINT | 17
54 | ATSAML21G18B-AUT | U1 | TQFP-48_L7.0-W7.0-P0.50-LS9.0-TL | 1 | ATSAML21G18B-AUT | MICROCHIP(美国微芯) | LCSC | C2052742 | 25.913
55 | XC6209F332MR-G | U2 | SOT-25-5_L3.0-W1.8-P0.95-LS3.0-BR | 1 | XC6209F332MR-G | TOREX(特瑞仕) | LCSC | C216624 | 0.175
56 | MC14043BDR2G | U3 | SOIC-16_L9.9-W3.9-P1.27-LS6.0-BL | 1 | MC14043BDR2G | onsemi(安森美) | LCSC | C233502 | 1.123
57 | LMV793MFX/NOPB | U4 | SOT-23-5_L2.9-W1.6-P0.95-LS2.8-BR | 1 | LMV793MFX/NOPB | TI(德州仪器) | LCSC | C2058263 | 4.314
58 | TPS7A2030PDBVR | U5 | TSOT-23-5_L2.9-W1.6-P0.95-LS2.8-BR | 1 | TPS7A2030PDBVR | TI(德州仪器) | LCSC | C963429 | 0.116
59 | TLV3201AIDBVT | U6 | SOT-23-5_L3.0-W1.7-P0.95-LS2.8-BR | 1 | TLV3201AIDBVT | TI(德州仪器) | LCSC | C83561 | 0.6
60 | OPA357AIDBVR | U7 | SOT-23-6_L2.9-W1.6-P0.95-LS2.8-BR | 1 | OPA357AIDBVR | TI(德州仪器) | LCSC | C139385 | 1.137
61 | TLR341G-GTR | U8,U14 | SSOP-6_L2.9-W1.6-P0.95-LS2.8-BR | 2 | TLR341G-GTR | ROHM(罗姆) | LCSC | C4366767 | 0.187
62 | 74LVC1G08GV,125 | U10 | SC-74A-5_L2.9-W1.6-P0.95-LS2.8-BL | 1 | 74LVC1G08GV,125 | Nexperia(安世) | LCSC | C282347 | 0.063
63 | LT3014BHVES5#TRMPBF | U11 | SOT-23-5_L3.0-W1.7-P0.95-LS2.8-BL | 1 | LT3014BHVES5#TRMPBF | ADI(亚德诺) | LCSC | C666252 | 3.214
64 | TXU0202DCUR | U12 | VSSOP-8 | 1 | TXB0102DCUR | TI(德州仪器) | LCSC | C60709 | 0.344
65 | TLV7031DBVR | U13 | SOT-23-5_L2.9-W1.6-P0.95-LS2.8-BR | 1 | TLV7031DBVR | TI(德州仪器) | LCSC | C2869832 | 0.735
66 | USB3.1C16PFSMT | USBC1 | USB-C-SMD_TYPE-C-USB-17 | 1 | - | LCSC | LCSC | C167321 | 0.357
67 | 32.768kHz | X1 | FC-135R_L3.2-W1.5 | 1 | Q13FC1350000400 | EPSON(爱普生) | LCSC | C32346 | 0.196

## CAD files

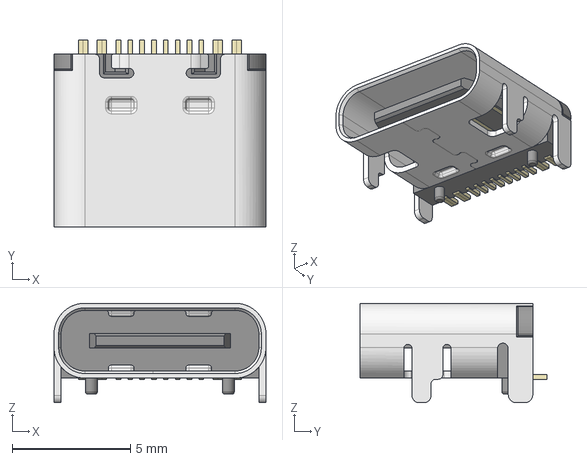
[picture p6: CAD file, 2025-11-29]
Polemo Core/bGeigieScint/HRO_TYPE-C-31-M-12.step
8.95 x 7.90 x 4.20 mm

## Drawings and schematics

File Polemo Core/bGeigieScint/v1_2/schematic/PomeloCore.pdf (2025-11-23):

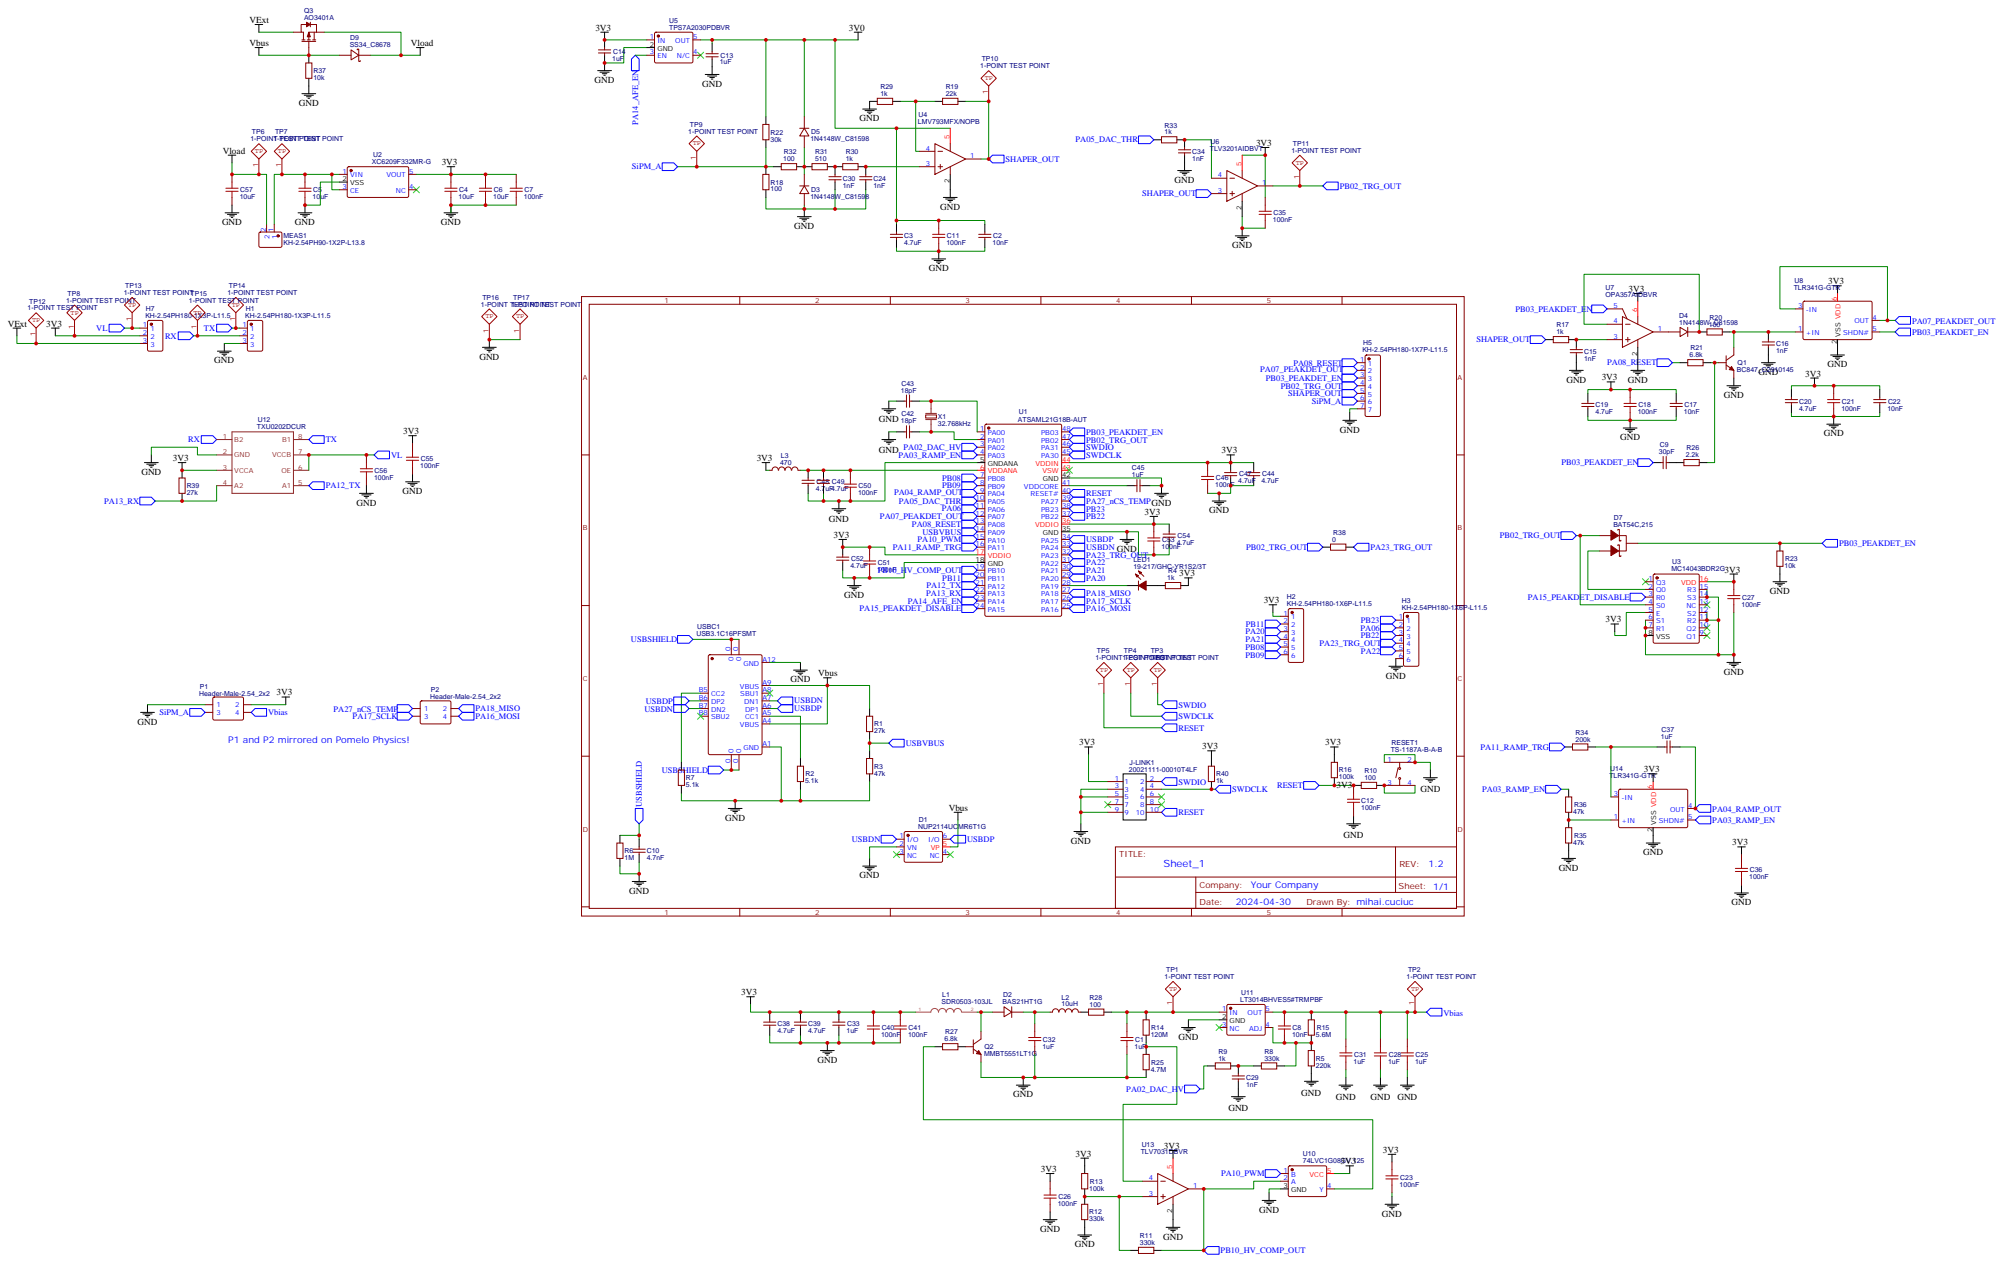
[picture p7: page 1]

P1 and P2 mirrored on Pomelo Physics!

Drawn By: mihai.cuciuc

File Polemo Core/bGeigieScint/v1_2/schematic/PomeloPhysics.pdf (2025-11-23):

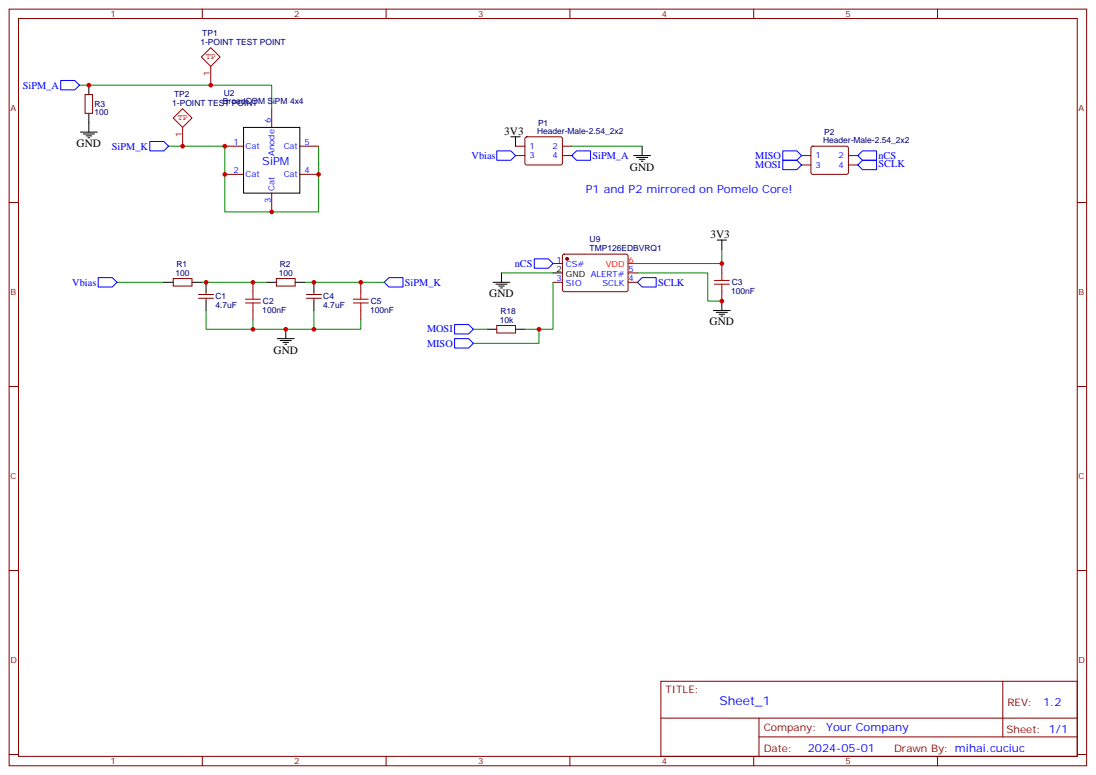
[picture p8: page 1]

P1 and P2 mirrored on Pomelo Core!

Drawn By: mihai.cuciuc

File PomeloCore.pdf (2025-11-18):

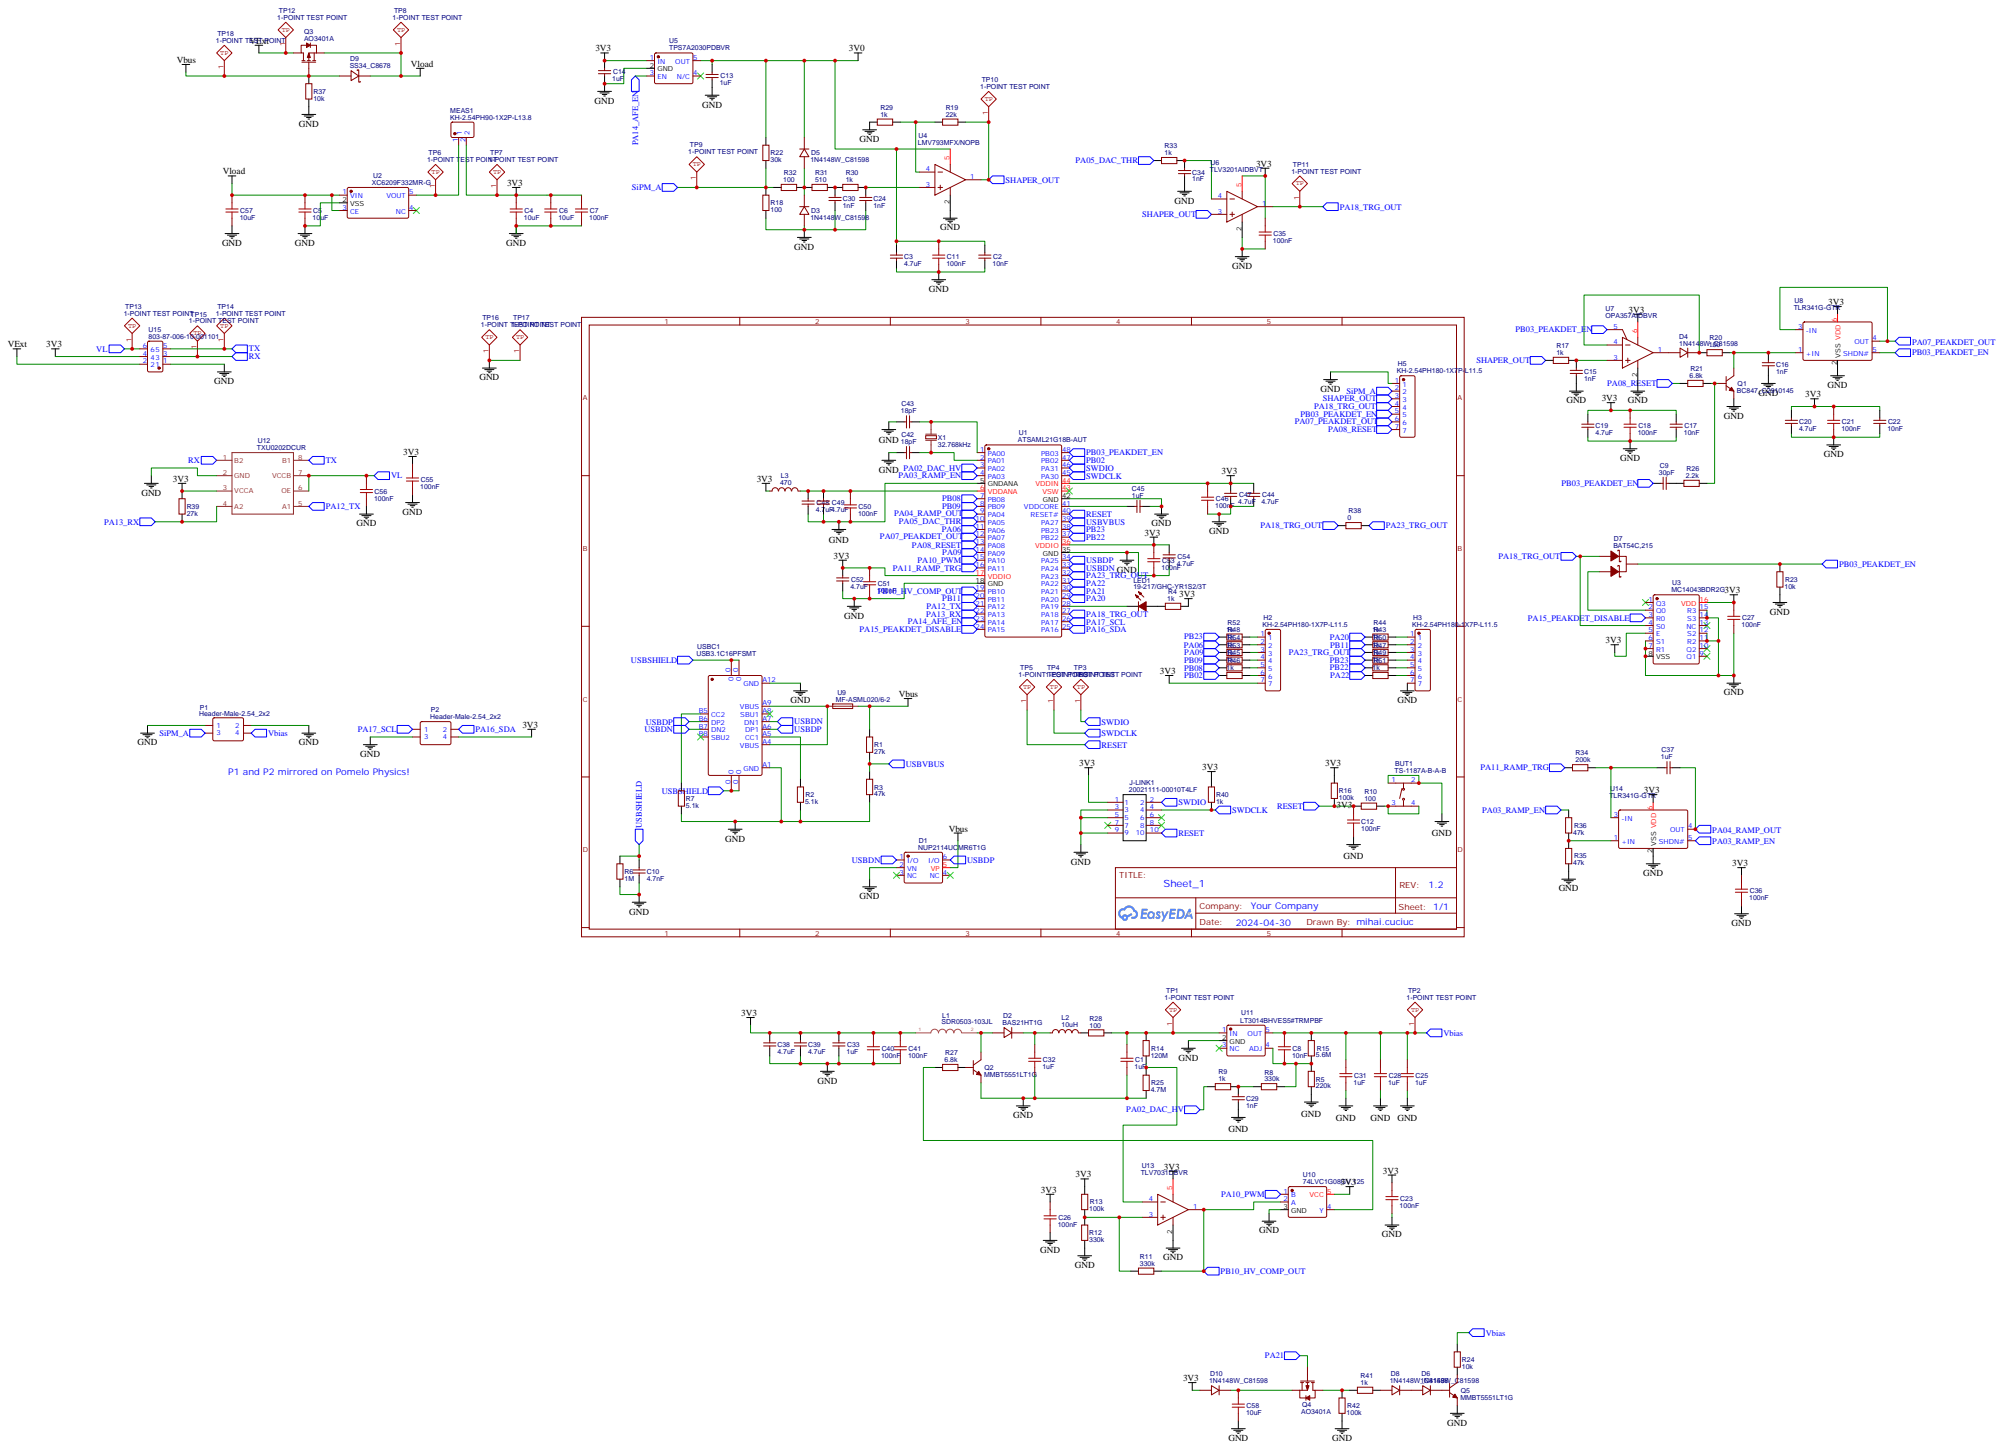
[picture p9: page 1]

P1 and P2 mirrored on Pomelo Physics!

Drawn By: mihai.cuciuc

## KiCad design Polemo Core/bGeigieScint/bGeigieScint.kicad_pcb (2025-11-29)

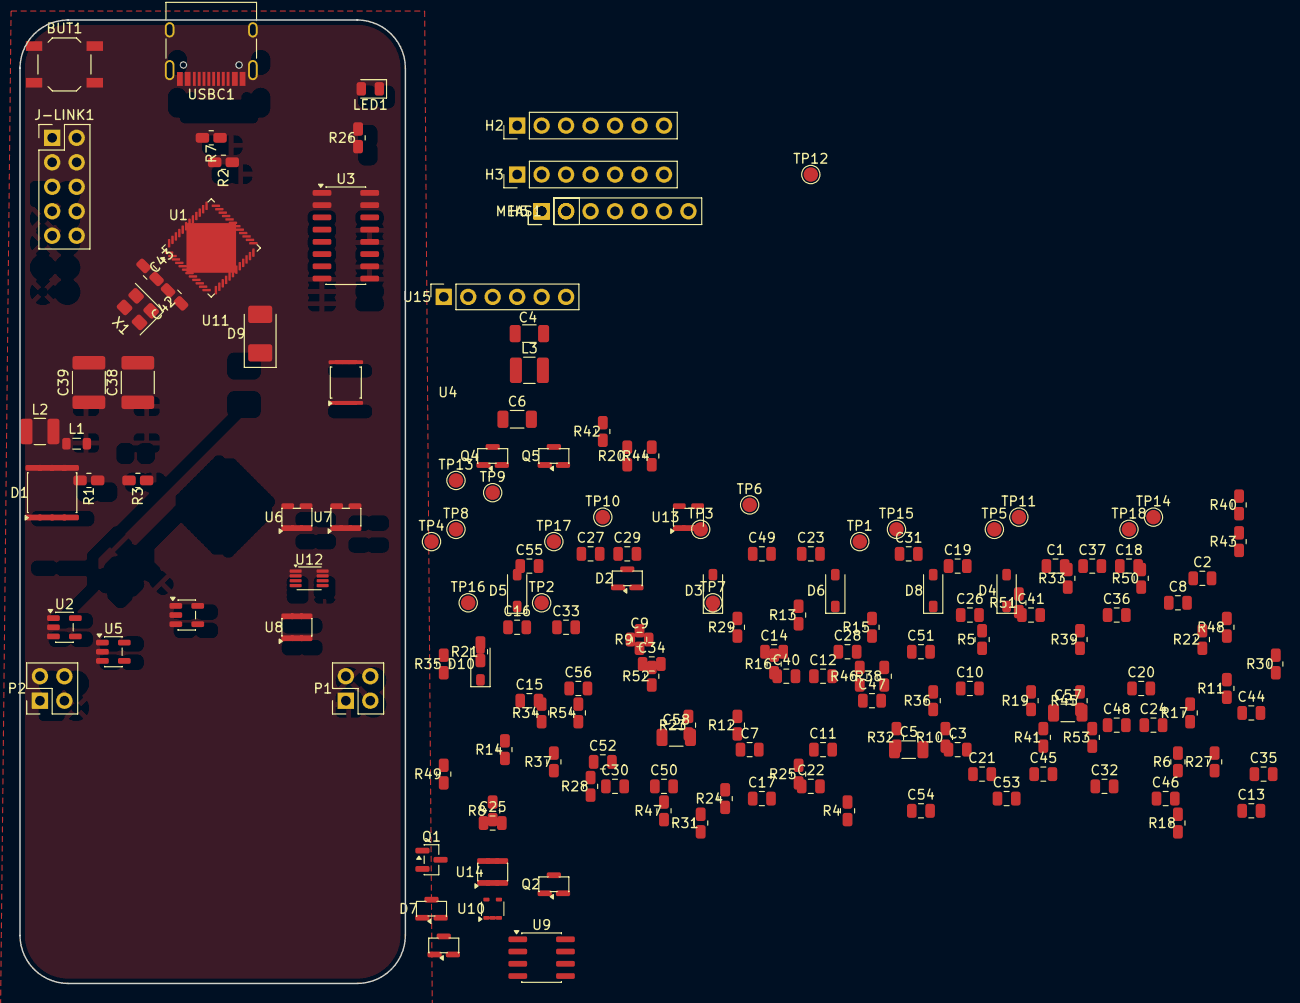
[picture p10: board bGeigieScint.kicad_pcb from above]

Board: 4 copper layers, 40.0 x 100.0 mm, 174 parts (0 on the bottom side), 99 nets, no tracks yet.

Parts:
BUT1: TS-1187A-B-A-B; SW_SPST_TL3342
C1, C13, C14, C25, C28, C31, C32, C33, C37, C45: 1uF; C_0805_2012Metric
C2, C8, C17, C22: 10nF; C_0805_2012Metric
C3, C19, C20, C44, C47, C48, C49, C52, C54: 4.7uF; C_0805_2012Metric
C4, C5, C6, C57, C58: 10uF; C_1206_3216Metric
C7, C11, C12, C18, C21, C23, C26, C27, C35, C36, C40, C41, C46, C50, C51, C53, C55, C56: 100nF; C_0805_2012Metric
C9: 30pF; C_0805_2012Metric
C10: 4.7nF; C_0805_2012Metric
C15, C16, C24, C29, C30, C34: 1nF; C_0805_2012Metric
C38, C39: 4.7uF; C_1812_4532Metric
C42, C43: 18pF; C_0805_2012Metric
D1: NUP2114UCMR6T1G; SO-8_3.9x4.9mm_P1.27mm
D2: BAS21HT1G; SOT-23
D3, D4, D5, D6, D8, D10: 1N4148W_C81598; D_SOD-123
D7: BAT54C,215; SOT-23
D9: SS34_C8678; D_SMA
H2, H3, H5: KH-2.54PH180-1X7P-L11.5; PinHeader_1x07_P2.54mm_Vertical
J-LINK1: 20021111-00010T4LF; PinHeader_2x05_P2.54mm_Vertical
L1: SDR0503-103JL; L_0805_2012Metric
L2: 10uH; L_1210_3225Metric
L3: 470Ω; L_1210_3225Metric
LED1: 19-217/GHC-YR1S2/3T; LED_0805_2012Metric
MEAS1: KH-2.54PH90-1X2P-L13.8; PinHeader_1x02_P2.54mm_Vertical
P1, P2: Header-Male-2.54_2x2; PinHeader_2x02_P2.54mm_Vertical
Q1: BC847_C2910145; SOT-23
Q2, Q5: MMBT5551LT1G; SOT-23
Q3, Q4: AO3401A; SOT-23
R1, R39: 27kΩ; R_0805_2012Metric
R2, R7: 5.1kΩ; R_0805_2012Metric
R3, R35, R36: 47kΩ; R_0805_2012Metric
R4, R9, R17, R29, R30, R33, R40, R41, R43, R44, R45, R46, R47, R48, R49, R50, R51, R52, R53, R54: 1kΩ; R_0805_2012Metric
R5: 220kΩ; R_0805_2012Metric
R6: 1MΩ; R_0805_2012Metric
R8, R11, R12: 330kΩ; R_0805_2012Metric
R10, R18, R20, R28, R32: 100Ω; R_0805_2012Metric
R13, R16, R42: 100kΩ; R_0805_2012Metric
R14: 120MΩ; R_0805_2012Metric
R15: 5.6MΩ; R_0805_2012Metric
R19: 22kΩ; R_0805_2012Metric
R21, R27: 6.8kΩ; R_0805_2012Metric
R22: 30kΩ; R_0805_2012Metric
R23, R24, R37: 10kΩ; R_0805_2012Metric
R25: 4.7MΩ; R_0805_2012Metric
R26: 2.2kΩ; R_0805_2012Metric
R31: 510Ω; R_0805_2012Metric
R34: 200kΩ; R_0805_2012Metric
R38: 0Ω; R_0805_2012Metric
TP1, TP2, TP3, TP4, TP5, TP6, TP7, TP8, TP9, TP10, TP11, TP12, TP13, TP14, TP15, TP16, TP17, TP18: 1-POINT TEST POINT; TestPoint_Pad_D1.5mm
U1: ATSAML21G18B-AUT; QFN-48-1EP_7x7mm_P0.5mm_EP5.15x5.15mm
U2: XC6209F332MR-G; SOT-23-5
U3: MC14043BDR2G; SOIC-16_3.9x9.9mm_P1.27mm
U4: LMV793MFX/NOPB; MSOP-8_3x3mm_P0.65mm
U5: TPS7A2030PDBVR; SOT-23-5
U6: TLV3201AIDBVT; SOT-23-5
U7: OPA357AIDBVR; SOT-23-5
U8, U14: TLR341G-GTR; SOT-23-6
U9: MF-ASML020/6-2; SOIC-8_3.9x4.9mm_P1.27mm
U10: 74LVC1G08GV,125; SOT-353_SC-70-5
U11: LT3014BHVES5#TRMPBF; SOT-23-5
U12: TXU0202DCUR; VSSOP-8_2.3x2mm_P0.5mm
U13: TLV7031DBVR; SOT-23-5
U15: 803-87-006-10-001101; PinSocket_1x06_P2.54mm_Vertical
USBC1: USB3.1C16PFSMT; USB_C_Receptacle_HRO_TYPE-C-31-M-12
X1: 32.768kHz; Crystal_SMD_3225-4Pin_3.2x2.5mm

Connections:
3V0: C2.2, C3.2, C11.2, C13.2, D5.1 (K), R22.2, U4.5 (V+), U5.5 (OUT)
3V3: C4.2, C6.2, C7.2, C14.2, C17.2, C18.2, C19.2, C20.2, C21.2, C22.2, C23.2, C26.2, C27.2, C33.2, C35.2, C36.2, C38.2, C39.2, C40.2, C41.2, C44.2, C46.2, C47.2, C51.2, C52.2, C53.2, C54.2, C55.2, D10.2 (A), H2.7, J-LINK1.1, L1.1, L3.1, MEAS1.2, P2.4, R4.2, R13.2, R16.2, R39.1, R40.2, TP7.1, U1.17 (VDDIO), U1.36 (VDDIO), U1.44 (VDDIN), U3.5 (E), U3.16 (VDD), U5.1 (IN), U6.5 (VCC), U8.6 (VDD), U10.5 (VCC), U12.2 (VCCA), U13.5 (VCC), U14.6 (VDD), U15.4
GND: BUT1.1 (A), BUT1.2 (B), C1.1, C2.1, C3.1, C4.1, C5.1, C6.1, C7.1, C10.1, C11.1, C12.2, C13.1, C14.1, C15.1, C16.1, C17.1, C18.1, C19.1, C20.1, C21.1, C22.1, C23.1, C24.1, C25.1, C26.1, C27.1, C28.1, C29.1, C30.1, C31.1, C32.1, C33.1, C34.1, C35.1, C36.1, C38.1, C39.1, C40.1, C41.1, C42.1, C43.1, C44.1, C45.1, C46.1, C47.1, C48.1, C49.1, C50.1, C51.1, C52.1, C53.1, C54.1, C55.1, C56.1, C57.1, C58.1, D1.2 (VN), D3.2 (A), H3.7, H5.1, J-LINK1.3, J-LINK1.5, J-LINK1.9, P1.1, P1.2, P2.3, Q1.2 (E), Q2.2 (E), Q5.2 (E), R2.1, R3.1, R5.1, R6.1, R7.1, R12.1, R18.1, R23.2, R25.1, R29.1, R35.1, R37.2, R42.1, TP16.1, TP17.1, U1.5 (GNDANA), U1.18 (GND), U1.35 (GND), U1.42 (GND), U2.2 (VSS), U3.6 (S1), U3.7 (R1), U3.8 (VSS), U3.11 (R2), U3.12 (S2), U3.14 (S3), U3.15 (R3), U4.2 (V-), U5.2 (GND), U6.2 (GND), U7.2 (V-), U8.2 (VSS), U10.3 (GND), U11.2 (GND), U12.5 (GND), U13.2 (VEE), U14.2 (VSS), U15.1, USBC1.A1 (GND), USBC1.A12 (GND)
unnamed: C9.2, R26.1
unnamed: C29.2, R8.1, R9.2
unnamed: C30.2, R30.1, R31.2
unnamed: D2.2 (A), L1.2, Q2.3 (C)
unnamed: C32.2, D2.1 (C), L2.1
unnamed: D3.1 (K), D5.2 (A), R31.1, R32.2
unnamed: D4.2 (A), U7.1 (OUT)
unnamed: D4.1 (K), R20.1, U7.4 (IN-)
unnamed: D6.2 (A), D8.1 (K)
unnamed: D6.1 (K), Q5.1 (B)
unnamed: D8.2 (A), R41.2
unnamed: C58.2, D10.1 (K), Q4.2 (S)
unnamed: H2.1, R52.1
unnamed: H2.2, R48.1
unnamed: H2.3, R54.1
unnamed: H2.4, R53.1
unnamed: H2.5, R45.1
unnamed: H2.6, R46.1
unnamed: H3.1, R44.1
unnamed: H3.2, R43.1
unnamed: H3.3, R50.1
unnamed: H3.4, R47.1
unnamed: H3.5, R49.1
unnamed: H3.6, R51.1
unnamed: L2.2, R28.2
unnamed: LED1.2 (A), R4.1
unnamed: LED1.1 (C), U1.28 (PA19)
unnamed: Q1.1 (B), R21.2, R26.2
unnamed: C16.2, Q1.3 (C), R20.2, U8.1 (+IN)
unnamed: Q2.1 (B), R27.2
unnamed: Q4.3 (D), R41.1, R42.2
unnamed: Q5.3 (C), R24.2
unnamed: C43.2, U1.1 (PA00), X1.2
unnamed: C42.2, U1.2 (PA01), X1.1
unnamed: C48.2, C49.2, C50.2, L3.2, U1.6 (VDDANA)
unnamed: C45.2, U1.41 (VDDCORE)
unnamed: MEAS1.1, TP6.1, U2.5 (VOUT)
unnamed: D7.2 (A), U3.2 (Q0)
unnamed: C24.2, R30.2, U4.3 (+IN)
unnamed: R19.1, R29.2, U4.4 (-IN)
unnamed: C34.2, R33.2, U6.4 (VIN-)
unnamed: U9.1, USBC1.A4 (VBUS), USBC1.A9 (VBUS)
unnamed: R27.1, U10.4 (Y)
unnamed: C8.1, R5.2, R8.2, R15.1, U11.4 (ADJ)
unnamed: C1.2, R14.2, R28.1, TP1.1, U11.1 (IN)
unnamed: R11.2, R12.2, R13.1, U13.3 (IN+)
unnamed: R14.1, R25.2, U13.4 (IN-)
unnamed: R35.2, R36.1, U14.1 (+IN)
unnamed: C37.2, R34.2, U14.3 (-IN)
unnamed: R2.2, USBC1.A5 (CC1)
unnamed: R7.2, USBC1.B5 (CC2)
PA02_DAC_HV: R9.1, U1.3 (PA02)
PA03_RAMP_EN: R36.2, U1.4 (PA03), U14.5 (SHDN#)
PA04_RAMP_OUT: C37.1, U1.9 (PA04), U14.4 (OUT)
PA05_DAC_THR: R33.1, U1.10 (PA05)
PA06: R48.2, U1.11 (PA06)
PA07_PEAKDET_OUT: H5.6, U1.12 (PA07), U8.3 (-IN), U8.4 (OUT)
PA08_RESET: H5.7, R21.1, U1.13 (PA08)
PA09: R54.2, U1.14 (PA09)
PA10_PWM: U1.15 (PA10), U10.1 (B)
PA11_RAMP_TRG: R34.1, U1.16 (PA11)
PA12_TX: U1.21 (PA12), U12.4 (A1)
PA13_RX: R39.2, U1.22 (PA13), U12.1 (A2)
PA14_AFE_EN: U1.23 (PA14), U5.3 (EN)
PA15_PEAKDET_DISABLE: U1.24 (PA15), U3.3 (R0)
PA16_SDA: P2.2, U1.25 (PA16)
PA17_SCL: P2.1, U1.26 (PA17)
PA18_TRG_OUT: D7.1 (A), H5.4, R38.1, TP11.1, U1.27 (PA18), U3.4 (S0), U6.1 (OUT)
PA20: R44.2, U1.29 (PA20)
PA21: Q4.1 (G), U1.30 (PA21)
PA22: R51.2, U1.31 (PA22)
PA23_TRG_OUT: R38.2, R50.2, U1.32 (PA23)
PB02: R46.2, U1.47 (PB02)
PB03_PEAKDET_EN: C9.1, D7.3 (K), H5.5, R23.1, U1.48 (PB03), U7.5 (ENABLE), U8.5 (SHDN#)
PB08: R45.2, U1.7 (PB08)
PB09: R53.2, U1.8 (PB09)
PB10_HV_COMP_OUT: R11.1, U1.19 (PB10), U10.2 (A), U13.1 (OUT)
PB11: R43.2, U1.20 (PB11)
PB22: R49.2, U1.37 (PB22)
PB23: R47.2, R52.2, U1.38 (PB23)
RESET: C12.1, J-LINK1.10, R10.1, R16.1, TP5.1, U1.40 (RESET#)
RX: TP15.1, U12.8 (B2), U15.3
SHAPER_OUT: C15.2, H5.3, R17.1, R17.2, R19.2, TP10.1, U4.1 (OUTPUT), U6.3 (VIN+), U7.3 (IN+)
SWDCLK: J-LINK1.4, R40.1, TP4.1, U1.45 (PA30)
SWDIO: J-LINK1.2, TP3.1, U1.46 (PA31)
SiPM_A: H5.2, P1.3, R18.2, R22.1, R32.1, TP9.1
TX: TP14.1, U12.6 (B1), U15.5
USBDN: D1.1 (I/O), U1.33 (PA24), USBC1.A7 (DN1), USBC1.B7 (DN2)
USBDP: D1.6 (I/O), U1.34 (PA25), USBC1.A6 (DP1), USBC1.B6 (DP2)
USBSHIELD: C10.2, R6.2
USBVBUS: R1.1, R3.2, U1.39 (PA27)
VExt: Q3.3 (D), TP12.1, U15.2
VL: C56.2, TP13.1, U12.3 (OE), U12.7 (VCCB), U15.6
Vbias: C8.2, C25.2, C28.2, C31.2, P1.4, R15.2, R24.1, TP2.1, U11.5 (OUT)
Vbus: D1.5 (VP), D9.2 (A), Q3.1 (G), R1.2, R37.1, TP18.1, U9.2
Vload: C5.2, C57.2, D9.1 (K), Q3.2 (S), TP8.1, U2.1 (VIN), U2.3 (CE)

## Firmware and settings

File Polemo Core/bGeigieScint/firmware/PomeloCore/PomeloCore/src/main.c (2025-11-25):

#include <asf.h>
#include <string.h>
#include <stdarg.h>
#include "conf_clocks.h"
#include "sio2host.h"
#include "nvm_params.h"

#define NVM_RWW				0x00400000

// Bootloader interface
#define DBL_TAP_PTR ((volatile uint32_t *)(HSRAM_ADDR + HSRAM_SIZE - 4))
#define DBL_TAP_MAGIC 0xf01669ef // Randomly selected, adjusted to have first and last bit set
#define SPECTRUM_LEN		1024
#define LIST_FIFO_LEN		128
#define UART_BUFFER_LEN		128

// bit numbers
#define LIST_UART_PULSE			0
#define LIST_UART_FAST_PULSE	1
#define LIST_UART_ENERGY		2
#define LIST_UART_ENERGY_TS		3
#define LIST_USB_PULSE			4
#define LIST_USB_ENERGY			5
#define LIST_USB_ENERGY_TS		6

typedef enum _UsbState_t
{
	STATE_CMD_IDLE,
	STATE_CMD_PARAM
}CmdState_t;


static struct core_params coreParams;
static struct physics_params physicsParams;

static float hvSipmVolts;

#define FILTER_LEN			4
extern const uint16_t pMove[1024][9];

static struct adc_module adc_instance_app;
static struct dac_module dac_instance_app;
static struct rtc_module rtc_instance_app;
struct spi_module spi_instance_app;
static struct i2c_master_module i2c_instance_app;
static struct tc_module tc_instance_app;
static struct tcc_module tcc_instance_app_pwm;

volatile static uint32_t hvloadTime;
volatile static uint32_t hvloadOn;
volatile static uint32_t hvloadOff;
static bool hvBoost;

volatile static uint32_t gammaTime;
volatile static uint32_t gammaCounts;
volatile static uint32_t gammaSum;
volatile static uint64_t gammaSumSquare;

volatile static uint32_t gammaPulseN, gammaPulseCoincidenceN;
volatile static uint32_t gammaPulseTstart, gammaPulseTstop;
volatile static bool gammaDaqRun, daq_enabled;
volatile static uint32_t gammaSpectrum[SPECTRUM_LEN];
volatile static uint32_t gammaSpectrumCoincidence[SPECTRUM_LEN];
volatile static uint16_t gammaFifo[LIST_FIFO_LEN];
volatile static uint32_t gammaFifoTs[LIST_FIFO_LEN];
volatile static uint16_t gammaFifoHead, gammaFifoTail;
volatile static bool gammaCoincidence;
volatile static bool gammaSyncTrig;
volatile static uint8_t gammaPulseChar;

volatile static uint8_t listOut;
volatile static bool temp_comp_run;

volatile bool usb_connected, can_sleep;
volatile bool isr_vbus;

static CmdState_t cmdState;

static struct usart_module app_uart_module;
static volatile uint8_t rxBufHead, rxBufTail;
static volatile uint8_t rxBuf[UART_BUFFER_LEN];

static void reset_to_bootloader(void);
void pomelo_printf(uint8_t iFace, const char* str);
int pomelo_sprintf(uint8_t iFace, const char * format, ... );


void USART_ISR_VECT(uint8_t instance)
{
	static uint16_t data;
	usart_read_wait(&app_uart_module, &data);

	if (rxBufHead != rxBufTail)
	{
		rxBuf[rxBufHead] = (uint8_t)data;
		rxBufHead = (rxBufHead + 1) % UART_BUFFER_LEN;
	}
}

bool uart_available()
{
	if ((rxBufTail + 1) % UART_BUFFER_LEN != rxBufHead) return true;
	else return false;
}

uint8_t uart_rx()
{
	rxBufTail = (rxBufTail + 1) % UART_BUFFER_LEN;
	return rxBuf[rxBufTail];
}

uint8_t uart_tx(uint8_t *data, uint8_t length)
{
	status_code_genare_t status;

	do {
		status = usart_serial_write_packet(&app_uart_module, (const uint8_t *)data, length);
	} while (status != STATUS_OK);
	return length;
}


void uart_init()
{
	struct usart_config host_uart_config;
	usart_get_config_defaults(&host_uart_config);
	host_uart_config.mux_setting = USART_RX_1_TX_0_XCK_1;
	host_uart_config.pinmux_pad0 = PINMUX_PA12C_SERCOM2_PAD0;
	host_uart_config.pinmux_pad1 = PINMUX_PA13C_SERCOM2_PAD1;
	host_uart_config.pinmux_pad2 = PINMUX_UNUSED;
	host_uart_config.pinmux_pad3 = PINMUX_UNUSED;
	//host_uart_config.baudrate    = 115200;
	host_uart_config.baudrate    = 921600;
	host_uart_config.run_in_standby = true;
	stdio_serial_init(&app_uart_module, SERCOM2, &host_uart_config);
	usart_enable(&app_uart_module);
	/* Enable transceivers */
	usart_enable_transceiver(&app_uart_module, USART_TRANSCEIVER_TX);
	usart_enable_transceiver(&app_uart_module, USART_TRANSCEIVER_RX);

	rxBufHead = 1;
	rxBufTail = 0;
	_sercom_set_handler(2, USART_ISR_VECT);
	SERCOM2->USART.INTENSET.reg = SERCOM_USART_INTFLAG_RXC;
	system_interrupt_enable(SYSTEM_INTERRUPT_MODULE_SERCOM2);
}


static void daq_stop(void)
{
	gammaPulseTstop = rtc_count_get_count(&rtc_instance_app);
	gammaDaqRun = false;
}

static void isr_vbus_callback(void)
{
	volatile uint8_t a;
	a = port_pin_get_input_level(PIN_PA27);
	isr_vbus = true;
}

static inline void timer_updateValues_unsafe()
{
	uint32_t timerCounts;
	timerCounts = tc_get_count_value(&tc_instance_app);
	gammaTime += timerCounts;
	hvloadTime += timerCounts;
	tc_set_count_value(&tc_instance_app, 0);
}


static void synchronizer_callback(void)
{
	if (listOut != 0)
	{
		if (gammaFifoHead != gammaFifoTail)
		{
			timer_updateValues_unsafe();

			gammaFifo[gammaFifoHead] = 9999;
			gammaFifoTs[gammaFifoHead] = gammaTime;
			gammaFifoHead++;
			if (gammaFifoHead >= LIST_FIFO_LEN)
			{
				gammaFifoHead = 0;
			}
		}
	}
}


static void trigger_callback(void)
{
	static uint16_t adc_val, rnd, i;
	static volatile bool pinValue;
	pinValue = port_pin_get_input_level(PIN_PA18);

	if (daq_enabled)
	{
		adc_start_conversion(&adc_instance_app);
		while (adc_read(&adc_instance_app, &adc_val) == STATUS_BUSY) ;

		// Clear peak detector capacitor
		port_pin_set_output_level(PIN_PA08, 1);
		port_pin_set_output_level(PIN_PA15, 1);
		nop(); nop(); nop(); nop(); nop(); // 5us. Aaaactually almost nothing
		port_pin_set_output_level(PIN_PA15, 0);
		port_pin_set_output_level(PIN_PA08, 0);


		if (gammaDaqRun)
		{
			port_pin_set_output_level(PIN_PA19, 0);
			
			adc_val >>= 2;
			
			if (pMove[adc_val][FILTER_LEN] > 0)
			{
				// Bin is a donor, figure out if we give it away
				if ((rand() % 32768) <= pMove[adc_val][FILTER_LEN])
				{
					// We give sample away. Let's figure out where
					rnd = rand() % 32768;
						
					for (i = 0; i < 2*FILTER_LEN+1; i++)
					{
						if (rnd <= pMove[adc_val][i]) break;
					}
					adc_val = adc_val - FILTER_LEN + i;
				}
			}
			
			gammaSpectrum[adc_val]++;
			gammaPulseN++;

			if (gammaCoincidence)
			{
				if (port_pin_get_input_level(PIN_PA20))
				{
					gammaSpectrumCoincidence[adc_val]++;
					gammaPulseCoincidenceN++;
					if (listOut != 0)
					{
						if (gammaFifoHead != gammaFifoTail)
						{
							timer_updateValues_unsafe();

							gammaFifo[gammaFifoHead] = adc_val;
							gammaFifoTs[gammaFifoHead] = gammaTime;
							gammaFifoHead++;
							if (gammaFifoHead >= LIST_FIFO_LEN)
							{
								gammaFifoHead = 0;
							}
						}
					}
					
					// Loop while monitor line is still high
					while (port_pin_get_input_level(PIN_PA20))
					{
						// Assert our ACK line if downstream detectors are also in ACK
						port_pin_set_output_level(PIN_PB11, port_pin_get_input_level(PIN_PA09));
					}
					// Deassert our ACK line
					port_pin_set_output_level(PIN_PB11, 0);
				}
			}
			else
			{
				if (listOut != 0)
				{
					// By now we're committed to suboptimal timing in our ISR,
					// so maybe we go all in and send the UART click pulse
					// directly
					if ((listOut & (1<<LIST_UART_FAST_PULSE)) != 0)
					{
						uart_tx(&gammaPulseChar, 1);
					}
					else if (gammaFifoHead != gammaFifoTail)
					{
						timer_updateValues_unsafe();

						gammaFifo[gammaFifoHead] = adc_val;
						gammaFifoTs[gammaFifoHead] = gammaTime;
						gammaFifoHead++;
						if (gammaFifoHead >= LIST_FIFO_LEN)
						{
							gammaFifoHead = 0;
						}
					}
				}
			}
			
			gammaCounts++;
			gammaSum += adc_val;
			gammaSumSquare += adc_val*adc_val;
			
		}

		port_pin_set_output_level(PIN_PA19, 1);
		
		// Try to fix subthreshold structures. Retriggering of this interrupt can
		// cause a 2nd reading, after the peak detector had already been cleared
		extint_chan_clear_detected(2);
	}
	
}


static void rtc_callback(void)
{
	daq_stop();
}

static void rtc_callback_periodic(void)
{
	static uint8_t d = 0;
	
	d++;
	if (d == 5)
	{
		d = 0;
		temp_comp_run = true;
		gammaSyncTrig = true;
	}
}


static void timer_callback(struct tc_module *const module)
{
	gammaTime += 65536;
	hvloadTime += 65536;
}


static void hvload_callback(void)
{
	static uint32_t tOn = 0;
	static uint32_t tOff = 0;
	static volatile bool pinValue;
	pinValue = port_pin_get_input_level(PIN_PB10);
	timer_updateValues_unsafe();
	if (pinValue)
	{
		tOff = hvloadTime;
		hvloadTime = 0;
		if (tOn != 0)
		{
			hvloadOn = tOn;
			hvloadOff = tOff;
			tOn = 0;
			tOff = 0;
		}
	}
	else
	{
		tOn = hvloadTime;
		hvloadTime = 0;
	}
}


static float hvload_uA()
{
	float iOut;
	
	if ((hvloadTime < 65535) && (hvloadOff != 0))
	{
		iOut = coreParams.iMeas[1] / hvloadOff + coreParams.iMeas[0];
		// 5.6 MOhm resistor in LT3014 feedback loop steals some current too. But resistor value is loaded from parameter
		if (coreParams.iMeas[2] != 0) iOut -= (hvSipmVolts - 1.22)/coreParams.iMeas[2];
		if (iOut < 0) iOut = 0;
	}
	else
	{
		iOut = 9999;
	}
	
	return iOut;
}

static void timer_init_gamma(void)
{
	struct tc_config tc_conf;
	
	tc_get_config_defaults(&tc_conf);
	tc_conf.clock_source = GCLK_GENERATOR_4;
	tc_conf.counter_size = TC_COUNTER_SIZE_16BIT;
	tc_conf.clock_prescaler = TC_CLOCK_PRESCALER_DIV1;
	tc_conf.count_direction = TC_COUNT_DIRECTION_UP;
	tc_conf.oneshot = false;
	tc_conf.run_in_standby = true;
	tc_init(&tc_instance_app, TC0, &tc_conf);
	
	tc_register_callback(&tc_instance_app, timer_callback, TC_CALLBACK_OVERFLOW);
	tc_enable_callback(&tc_instance_app, TC_CALLBACK_OVERFLOW);

	tc_enable(&tc_instance_app);
}

static void coincidences_reset(void)
{
	struct port_config pin_conf;

	ccl_module_reset();
	
	// All pins set as inputs with pull-down enabled
	port_get_config_defaults(&pin_conf);
	pin_conf.direction  = PORT_PIN_DIR_INPUT;
	pin_conf.input_pull = SYSTEM_PINMUX_PIN_PULL_DOWN;

	// CCL2 and CCL0 inputs and outputs
	port_pin_set_config(PIN_PA23, &pin_conf);
	port_pin_set_config(PIN_PA22, &pin_conf);
	port_pin_set_config(PIN_PB22, &pin_conf);
	port_pin_set_config(PIN_PB09, &pin_conf);
	port_pin_set_config(PIN_PB23, &pin_conf);
	
	// Software clear mechanism inputs and output
	port_pin_set_config(PIN_PA20, &pin_conf);
	port_pin_set_config(PIN_PA09, &pin_conf);
	port_pin_set_config(PIN_PB11, &pin_conf);
	
	// Also handle synchronization config
	port_pin_set_config(PIN_PB02, &pin_conf);
}

static void coincidences_enable(void)
{
	struct ccl_config ccl_conf;
	struct ccl_lut_config ccl_lut_conf;
	struct system_pinmux_config pinmux_config;
	struct port_config pin_conf;

	// Coincidences synchronizer output
	pin_conf.direction  = PORT_PIN_DIR_OUTPUT;
	port_pin_set_config(PIN_PB02, &pin_conf);
	port_pin_set_output_level(PIN_PB02, 0);
	
	// ACK output
	pin_conf.direction  = PORT_PIN_DIR_OUTPUT;
	port_pin_set_config(PIN_PB11, &pin_conf);
	port_pin_set_output_level(PIN_PB11, 0);
	
	// Set PA22 as remote trigger input - CCL2 In0
	system_pinmux_get_config_defaults(&pinmux_config);
	pinmux_config.mux_position = 8;
	pinmux_config.direction    = SYSTEM_PINMUX_PIN_DIR_INPUT;
	pinmux_config.input_pull   = SYSTEM_PINMUX_PIN_PULL_DOWN;
	system_pinmux_pin_set_config(PIN_PA22, &pinmux_config);

	// Set PA23 as local trigger input - CCL2 In1
	system_pinmux_get_config_defaults(&pinmux_config);
	pinmux_config.mux_position = 8;
	pinmux_config.direction    = SYSTEM_PINMUX_PIN_DIR_INPUT;
	pinmux_config.input_pull   = SYSTEM_PINMUX_PIN_PULL_DOWN;
	system_pinmux_pin_set_config(PIN_PA23, &pinmux_config);

	// Set PB09 as coincidences output - CCL2 out
	system_pinmux_get_config_defaults(&pinmux_config);
	pinmux_config.mux_position = 8;
	pinmux_config.direction    = SYSTEM_PINMUX_PIN_DIR_OUTPUT_WITH_READBACK;
	system_pinmux_pin_set_config(PIN_PB09, &pinmux_config);

	// Set PB22 as ACK0 input - CCL0 In0
	system_pinmux_get_config_defaults(&pinmux_config);
	pinmux_config.mux_position = 8;
	pinmux_config.direction    = SYSTEM_PINMUX_PIN_DIR_INPUT;
	pinmux_config.input_pull   = SYSTEM_PINMUX_PIN_PULL_DOWN;
	system_pinmux_pin_set_config(PIN_PB22, &pinmux_config);

	// Set PB23 as coincidences output - CCL0 out
	system_pinmux_get_config_defaults(&pinmux_config);
	pinmux_config.mux_position = 8;
	pinmux_config.direction    = SYSTEM_PINMUX_PIN_DIR_OUTPUT_WITH_READBACK;
	system_pinmux_pin_set_config(PIN_PB23, &pinmux_config);

	ccl_module_reset();

	// Make coincidence trigger logic
	ccl_get_config_defaults(&ccl_conf);
	ccl_conf.run_in_standby = true;
	ccl_conf.clock_source = GCLK_GENERATOR_0;
	ccl_init(&ccl_conf);

	// LUT2: In0 Remote trigger, In1 Local trigger, In2 Lnk
	ccl_lut_get_config_defaults(&ccl_lut_conf);
	ccl_lut_conf.edge_selection_enable = false;
	ccl_lut_conf.event_input_enable = false;
	ccl_lut_conf.event_output_enable = false;
	ccl_lut_conf.filter_sel = CCL_LUT_FILTER_DISABLE;
	ccl_lut_conf.input0_src_sel = CCL_LUT_INPUT_SRC_IO;
	ccl_lut_conf.input1_src_sel = CCL_LUT_INPUT_SRC_IO;
	ccl_lut_conf.input2_src_sel = CCL_LUT_INPUT_SRC_LINK;
	ccl_lut_conf.truth_table_value = 0xF8;		// (In0 AND In1) OR In2
	ccl_lut_set_config(CCL_LUT_2, &ccl_lut_conf);

	// LUT0: In0 ACK, In1: Lnk; ACK0 reset, output to pin
	ccl_lut_get_config_defaults(&ccl_lut_conf);
	ccl_lut_conf.edge_selection_enable = false;
	ccl_lut_conf.event_input_enable = false;
	ccl_lut_conf.event_output_enable = false;
	ccl_lut_conf.filter_sel = CCL_LUT_FILTER_DISABLE;
	ccl_lut_conf.input0_src_sel = CCL_LUT_INPUT_SRC_IO;
	ccl_lut_conf.input1_src_sel = CCL_LUT_INPUT_SRC_LINK;
	ccl_lut_conf.input2_src_sel = CCL_LUT_INPUT_SRC_MASK;
	ccl_lut_conf.truth_table_value = 0x44;	// In1 AND NOT In0
	ccl_lut_set_config(CCL_LUT_0, &ccl_lut_conf);

	// LUT1: Pass
	ccl_lut_get_config_defaults(&ccl_lut_conf);
	ccl_lut_conf.edge_selection_enable = false;
	ccl_lut_conf.event_input_enable = false;
	ccl_lut_conf.event_output_enable = false;
	ccl_lut_conf.filter_sel = CCL_LUT_FILTER_DISABLE;
	ccl_lut_conf.input0_src_sel = CCL_LUT_INPUT_SRC_LINK;
	ccl_lut_conf.input1_src_sel = CCL_LUT_INPUT_SRC_MASK;
	ccl_lut_conf.input2_src_sel = CCL_LUT_INPUT_SRC_MASK;
	ccl_lut_conf.truth_table_value = 0x02;
	ccl_lut_set_config(CCL_LUT_1, &ccl_lut_conf);

	// LUT3: Pass
	ccl_lut_get_config_defaults(&ccl_lut_conf);
	ccl_lut_conf.edge_selection_enable = false;
	ccl_lut_conf.event_input_enable = false;
	ccl_lut_conf.event_output_enable = false;
	ccl_lut_conf.filter_sel = CCL_LUT_FILTER_DISABLE;
	ccl_lut_conf.input0_src_sel = CCL_LUT_INPUT_SRC_LINK;
	ccl_lut_conf.input1_src_sel = CCL_LUT_INPUT_SRC_MASK;
	ccl_lut_conf.input2_src_sel = CCL_LUT_INPUT_SRC_MASK;
	ccl_lut_conf.truth_table_value = 0x02;
	ccl_lut_set_config(CCL_LUT_3, &ccl_lut_conf);
	
	ccl_lut_enable(CCL_LUT_0);
	ccl_lut_enable(CCL_LUT_1);
	ccl_lut_enable(CCL_LUT_2);
	ccl_lut_enable(CCL_LUT_3);
	
	ccl_module_enable();
}
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
int main(void)
{
	system_init();

	power_config();		// ?? No idea if this actually does anything
	
	struct port_config pin_conf;
	port_get_config_defaults(&pin_conf);
	
	// LED
	pin_conf.direction  = PORT_PIN_DIR_OUTPUT;
	port_pin_set_config(PIN_PA19, &pin_conf);
	port_pin_set_output_level(PIN_PA19, 1);

	// Reset cap
	pin_conf.direction  = PORT_PIN_DIR_OUTPUT;
	port_pin_set_config(PIN_PA08, &pin_conf);
	port_pin_set_output_level(PIN_PA08, 0);

	// USBVBUS
	pin_conf.direction  = PORT_PIN_DIR_INPUT;
	pin_conf.input_pull = PORT_PIN_PULL_NONE;
	port_pin_set_config(PIN_PA27, &pin_conf);

	// AFE_EN
	pin_conf.direction  = PORT_PIN_DIR_OUTPUT;
	port_pin_set_config(PIN_PA14, &pin_conf);
	port_pin_set_output_level(PIN_PA14, 1);

	// PeakDet disable
	pin_conf.direction  = PORT_PIN_DIR_OUTPUT;
	port_pin_set_config(PIN_PA15, &pin_conf);
	port_pin_set_output_level(PIN_PA15, 0);

	// Ramp generator enable
	pin_conf.direction  = PORT_PIN_DIR_OUTPUT;
	port_pin_set_config(PIN_PA03, &pin_conf);
	port_pin_set_output_level(PIN_PA03, 0);

	// Ramp generator trigger
	pin_conf.direction  = PORT_PIN_DIR_OUTPUT;
	port_pin_set_config(PIN_PA11, &pin_conf);
	port_pin_set_output_level(PIN_PA11, 0);

	// Ramp generator input
	pin_conf.direction  = PORT_PIN_DIR_INPUT;
	port_pin_set_config(PIN_PA04, &pin_conf);

	// Trigger input
	pin_conf.direction  = PORT_PIN_DIR_INPUT;
	port_pin_set_config(PIN_PA18, &pin_conf);

	// Synchronizer input
	pin_conf.direction  = PORT_PIN_DIR_INPUT;
	port_pin_set_config(PIN_PB08, &pin_conf);

	// PeakDet EN input (2nd trigger)
	pin_conf.direction  = PORT_PIN_DIR_INPUT;
	port_pin_set_config(PIN_PB03, &pin_conf);

	// HV crowbar. Active low, to engage it when board power is switched off
	pin_conf.direction  = PORT_PIN_DIR_OUTPUT;
	port_pin_set_config(PIN_PA21, &pin_conf);
	port_pin_set_output_level(PIN_PA21, 1);
	
	// HV load measurement
	pin_conf.direction  = PORT_PIN_DIR_INPUT;
	pin_conf.input_pull = PORT_PIN_PULL_NONE;
	port_pin_set_config(PIN_PB10, &pin_conf);


	// Paranoid, just make sure HV PWM starts off
	hvBoost = false;
	hv_disable();

	// Clear peak detector capacitor
	port_pin_set_output_level(PIN_PA08, 1);
	nop(); nop(); nop(); nop(); nop(); // 5us
	nop(); nop(); nop(); nop(); nop(); // 5us
	nop(); nop(); nop(); nop(); nop(); // 5us
	nop(); nop(); nop(); nop(); nop(); // 5us
	nop(); nop(); nop(); nop(); nop(); // 5us
	nop(); nop(); nop(); nop(); nop(); // 5us
	port_pin_set_output_level(PIN_PA08, 0);

	unused_pins_init();

	// MCHP: host_uart_config.generator_source = GCLK_GENERATOR_3; added to init()

	rtc_init_gamma();
	eic_init();

	configure_nvm();

	isr_vbus = false;
	can_sleep = true;
	daq_enabled = false;
	temp_comp_run = false;

	gammaDaqRun = false;
	gammaCoincidence = false;
	gammaSyncTrig = false;
	listOut = 0;

	hvloadTime = 0;

	// Start with USB enabled. Will be switched off by main loop if required
	usb_connected = true;
	main_clock_select_dfll();
	udc_start();

	uart_init();
	adc_init_gamma();
	coincidences_reset();
	timer_init_gamma();

	// Do this to have a consistent state
	dac_init_gamma_hv();
	dac_chan_write(&dac_instance_app, DAC_CHANNEL_0, 4095);	// Immediately set a value that drives HV as low as possible
	dac_chan_write(&dac_instance_app, DAC_CHANNEL_1, 4095);
	daq_enabled = true;
	pomelo_off();

	i2c_init();

	load_parameters();
	apply_parameters();

	temp_init();


	while(1)
	{
		if (usb_connected)
		{
			usb_data_handler();
		}
		
		uart_data_handler();
		
		if (listOut != 0)
		{
			if (((gammaFifoTail + 1) % LIST_FIFO_LEN) != gammaFifoHead)
			{
				gammaFifoTail++;
				if (gammaFifoTail >= LIST_FIFO_LEN)
				{
					gammaFifoTail = 0;
				}
				if ((listOut & (1<<LIST_UART_PULSE)) != 0) uart_tx(&gammaPulseChar, 1);
				if ((listOut & (1<<LIST_UART_ENERGY)) != 0) pomelo_sprintf(1, "%d\n", gammaFifo[gammaFifoTail]);
				if ((listOut & (1<<LIST_UART_ENERGY_TS)) != 0) pomelo_sprintf(1, "%lu,%d\n", gammaFifoTs[gammaFifoTail], gammaFifo[gammaFifoTail]);
				if ((listOut & (1<<LIST_USB_PULSE)) != 0) pomelo_sprintf(0, "%c", gammaPulseChar);
				if ((listOut & (1<<LIST_USB_ENERGY)) != 0) pomelo_sprintf(0, "%d\n", gammaFifo[gammaFifoTail]);
				if ((listOut & (1<<LIST_USB_ENERGY_TS)) != 0) pomelo_sprintf(0, "%lu,%d\n", gammaFifoTs[gammaFifoTail], gammaFifo[gammaFifoTail]);

				can_sleep = false;
			}
			else
			{
				can_sleep = true;
			}
		}

		if (isr_vbus)
		{
			// Switch on USB and turn off low power mode
			usb_connected = true;
			cmdState = STATE_CMD_IDLE;
			main_clock_select_dfll();
			udc_start();
			isr_vbus = false;
		}

		if ((port_pin_get_input_level(PIN_PA27) == 0) && usb_connected)
		{
			// VBUS line is low, USB unplugged. Switch off USB and enable low power mode
			usb_connected = false;
			cmdState = STATE_CMD_IDLE;
			// MCHP: Add "usb_disable(&usb_device);" at the end of udd_disable() in usb_device_udd.c
			udc_stop();
			main_clock_select_osc16m();
			unused_pins_init();
		}
		
		if (temp_comp_run)
		{
			if (daq_enabled) update_hv_temp(false);
			temp_comp_run = false;
		}
		
		if (gammaSyncTrig)
		{
			port_pin_set_output_level(PIN_PB02, 1);
			nop(); nop(); nop(); nop(); nop(); // 5us. Aaaactually almost nothing
			port_pin_set_output_level(PIN_PB02, 0);
			gammaSyncTrig = false;
		}
		
		if (can_sleep && !usb_connected)
		{
			system_set_sleepmode(SYSTEM_SLEEPMODE_STANDBY);
			system_sleep();
		}
	}
}


void pomelo_printf(uint8_t iFace, const char* str)
{
	if (iFace == 0)
	{
		if (usb_connected)
		{
			udi_cdc_multi_write_buf(1,str,strlen(str));
		}
	}
	else if (iFace == 1)
	{
		uart_tx(str,strlen(str));
	}
}

int pomelo_sprintf(uint8_t iFace, const char * format, ... )
{
	static char str[80];
	static va_list args;

	if (iFace == 0)
	{
		if (usb_connected)
		{
			va_start(args, format);
			vsprintf(str,format, args);
			va_end(args);
			udi_cdc_multi_write_buf(1,str,strlen(str));
		}
	}
	else if (iFace == 1)
	{
		va_start(args, format);
		vsprintf(str,format, args);
		va_end(args);
		uart_tx(str,strlen(str));
	}
	return 0;
}

static void reset_to_bootloader(void)
{
	*DBL_TAP_PTR = DBL_TAP_MAGIC;
	NVIC_SystemReset();
}

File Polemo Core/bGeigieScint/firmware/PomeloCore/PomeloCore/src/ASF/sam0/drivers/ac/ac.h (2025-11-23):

/**
 * \file
 *
 * \brief SAM Analog Comparator Driver
 *
 * Copyright (c) 2012-2020 Microchip Technology Inc. and its subsidiaries.
 *
 * \asf_license_start
 *
 * \page License
 *
 * Subject to your compliance with these terms, you may use Microchip
 * software and any derivatives exclusively with Microchip products.
 * It is your responsibility to comply with third party license terms applicable
 * to your use of third party software (including open source software) that
 * may accompany Microchip software.
 *
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
 * \asf_license_stop
 *
 */
/*
 * Support and FAQ: visit <a href="https://www.microchip.com/support/">Microchip Support</a>
 */
#ifndef AC_H_INCLUDED
#define AC_H_INCLUDED

/**
 * \defgroup asfdoc_sam0_ac_group SAM Analog Comparator (AC) Driver
 *
 * This driver for Atmel&reg; | SMART ARM&reg;-based microcontrollers
 * provides an interface for the configuration
 * and management of the device's Analog Comparator functionality, for the
 * comparison of analog voltages against a known reference voltage to determine
 * its relative level. The following driver API modes are covered by this
 * manual:
 * - Polled APIs
 * \if AC_CALLBACK_MODE
 * - Callback APIs
 * \endif
 *
 * The following peripherals are used by this module:
 *  - AC (Analog Comparator)
 *
 * The following devices can use this module:
 *  - Atmel | SMART SAM D20/D21
 *  - Atmel | SMART SAM R21
 *  - Atmel | SMART SAM D10/D11
 *  - Atmel | SMART SAM L21/L22
 *  - Atmel | SMART SAM DA1
 *  - Atmel | SMART SAM C20/C21
 *  - Atmel | SMART SAM HA1
 *  - Atmel | SMART SAM R34/R35
 *
 * The outline of this documentation is as follows:
 *  - \ref asfdoc_sam0_ac_prerequisites
 *  - \ref asfdoc_sam0_ac_module_overview
 *  - \ref asfdoc_sam0_ac_special_considerations
 *  - \ref asfdoc_sam0_ac_extra_info
 *  - \ref asfdoc_sam0_ac_examples
 *  - \ref asfdoc_sam0_ac_api_overview
 *
 *
 * \section asfdoc_sam0_ac_prerequisites Prerequisites
 *
 * There are no prerequisites for this module.
 *
 *
 * \section asfdoc_sam0_ac_module_overview Module Overview
 *
 * The Analog Comparator module provides an interface for the comparison of one
 * or more analog voltage inputs (sourced from external or internal inputs)
 * against a known reference voltage, to determine if the unknown voltage is
 * higher or lower than the reference. Additionally, window functions are
 * provided so that two comparators can be connected together to determine if
 * an input is below, inside, above, or outside the two reference points of the
 * window.
 *
 * Each comparator requires two analog input voltages, a positive and negative
 * channel input. The result of the comparison is a binary \c true if the
 * comparator's positive channel input is higher than the comparator's negative
 * input channel, and \c false if otherwise.
 *
 *
 * \subsection asfdoc_sam0_ac_module_features Driver Feature Macro Definition
 * <table>
 *    <tr>
 *      <th>Driver Feature Macro</th>
 *      <th>Supported devices</th>
 *    </tr>
 *    <tr>
 *      <td>FEATURE_AC_HYSTERESIS_LEVEL</td>
 *      <td>SAM L21/L22/C20/C21/R34/R35</td>
 *    </tr>
 *    <tr>
 *      <td>FEATURE_AC_SYNCBUSY_SCHEME_VERSION_2</td>
 *      <td>SAM L21/L22/C20/C21/R34/R35</td>
 *    </tr>
 *    <tr>
 *      <td>FEATURE_AC_RUN_IN_STANDY_EACH_COMPARATOR</td>
 *      <td>SAM L21/L22/C20/C21/R34/R35</td>
 *    </tr>
 *    <tr>
 *      <td>FEATURE_AC_RUN_IN_STANDY_PAIR_COMPARATOR</td>
 *      <td>SAM D20/L22/D21/D10/D11/R21/DA1/HA1/R34/R35</td>
 *    </tr>
 * </table>
 * \note The specific features are only available in the driver when the
 * selected device supports those features.
 *
 * \subsection asfdoc_sam0_ac_module_overview_pairs Window Comparators and Comparator Pairs
 * Each comparator module contains one or more comparator pairs, a set of two
 * distinct comparators which can be used independently or linked together for
 * Window Comparator mode. In this latter mode, the two comparator units in a
 * comparator pair are linked together to allow the module to detect if an input
 * voltage is below, inside, above, or outside a window set by the upper and
 * lower threshold voltages set by the two comparators. If not required, window
 * comparison mode can be turned off and the two comparator units can be
 * configured and used separately.
 *
 * \subsection asfdoc_sam0_ac_module_overview_pos_neg_mux Positive and Negative Input MUXes
 * Each comparator unit requires two input voltages, a positive and a negative
 * channel (note that these names refer to the logical operation that the unit
 * performs, and both voltages should be above GND), which are then compared with
 * one another. Both the positive and the negative channel inputs are connected to
 * a pair of multiplexers (MUXes), which allows one of several possible inputs to be
 * selected for each comparator channel.
 *
 * The exact channels available for each comparator differ for the positive and
 * the negative inputs, but the same MUX choices are available for all comparator
 * units (i.e. all positive MUXes are identical, all negative MUXes are
 * identical). This allows the user application to select which voltages are
 * compared to one another.
 *
 * When used in window mode, both comparators in the window pair should have
 * their positive channel input MUXes configured to the same input channel, with
 * the negative channel input MUXes used to set the lower and upper window
 * bounds.
 *
 * \subsection asfdoc_sam0_ac_module_overview_output_filtering Output Filtering
 * The output of each comparator unit can either be used directly with no
 * filtering (giving a lower latency signal, with potentially more noise around
 * the comparison threshold) or be passed through a multiple stage
 * digital majority filter. Several filter lengths are available, with the
 * longer stages producing a more stable result, at the expense of a higher
 * latency.
 *
 * When output filtering is used in single shot mode, a single trigger of the
 * comparator will automatically perform the required number of samples to
 * produce a correctly filtered result.
 *
 * \subsection asfdoc_sam0_ac_module_overview_input_hysteresis Input Hysteresis
 * To prevent unwanted noise around the threshold where the comparator unit's
 * positive and negative input channels are close in voltage to one another, an
 * optional hysteresis can be used to widen the point at which the output result
 * flips. This mode will prevent a change in the comparison output unless the
 * inputs cross one another beyond the hysteresis gap introduces by this mode.
 *
 * \subsection asfdoc_sam0_ac_module_overview_sampling Single Shot and Continuous Sampling Modes
 * Comparators can be configured to run in either Single Shot or Continuous
 * sampling modes; when in Single Shot mode, the comparator will only perform a
 * comparison (and any resulting filtering, see
 * \ref asfdoc_sam0_ac_module_overview_output_filtering) when triggered via a
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

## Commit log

2025-11-18 Create Initial PomeloCore schematic
2025-11-18 Added PDF of schematic
2025-11-22 Add scripts for assigning footprints to PomeloCore schematic components
    - Implemented assign_footprints_correct.py for initial footprint assignment.
    - Developed assign_footprints_final.py to assign footprints to actual component instances.
    - Created assign_footprints_v2.py to handle KiCad 9 format with symbol instances.
    - Introduced assign_footprints_v3.py to overwrite existing footprints correctly.
    - Added assign_fp_working.py for a streamlined footprint assignment process.
    - Enhanced footprint mapping for various components including resistors, capacitors, diodes, and inductors.
    - Improved regex parsing for extracting component references and values.
    - Added print statements for tracking a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
    [Polemo Core 2.kicad_pcb, Polemo Core 2.kicad_sch, Polemo Core.kicad_pcb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]
2025-11-23 Added V1.2 files
    [BOM.csv, Polemo Core 2.kicad_pcb]
2025-11-23 Moved more components around
    [Polemo Core 2.kicad_pcb, Polemo Core 2.kicad_sch]
2025-11-25 Added source code for the firmw.are
    [Polemo Core 2.kicad_sch]
2025-11-25 feat: Implement initial project setup for PomeloCore firmware, integrating ASF core, SAM L21 drivers, and project configuration files.
2025-11-29 Added README.md and update many files
    [Polemo Core 2.kicad_pcb, Polemo Core 2.kicad_sch]
2025-11-29 moved many files
    [BOM.csv, HRO_TYPE-C-31-M-12.step, Polemo Core 2.dsn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]

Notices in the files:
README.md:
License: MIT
